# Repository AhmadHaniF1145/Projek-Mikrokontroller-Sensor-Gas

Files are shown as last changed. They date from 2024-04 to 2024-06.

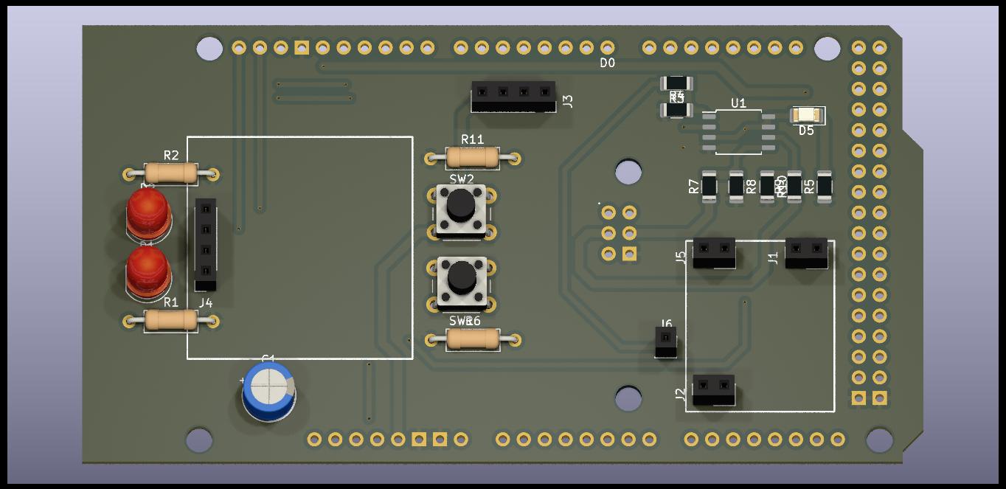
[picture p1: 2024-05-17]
Assets/PCB Design/Pre/3D PCB Design/2.jpg

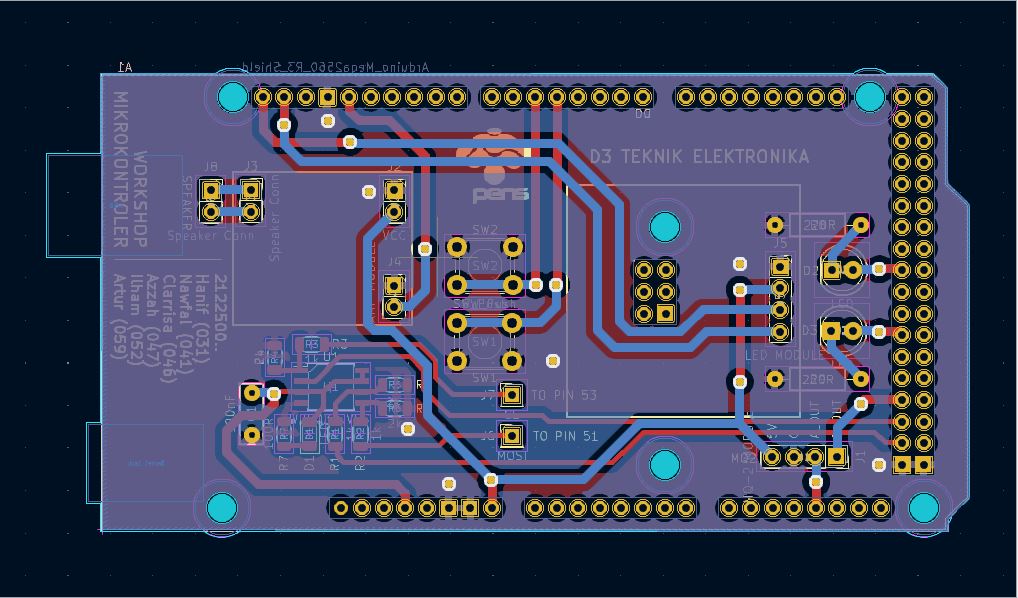
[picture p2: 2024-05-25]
Assets/PCB Design/Final/BOTTOM.JPG

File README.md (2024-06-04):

banner-dg-logo
Sistem pendeteksi kebocoran gas adalah sistem elektronik yang dirancang untuk mendeteksi dan memberi peringatan tentang kebocoran gas. Peringatan yang dihasilkan adalah dalam bentuk audio sesuai gas yang dideteksi beserta tingkat bahayanya.

`WORKSHOP MIKROKONTROLLER - PROGRAM STUDI TEKNIK ELEKTRONIKA - POLITEKNIK ELEKTRONIKA NEGERI SURABAYA`

`DOSEN PENGAMPU : Akhmad Hendriawan ST, MT`
`NIP. 197501272002121003`

`TEAM`
| No.  | Nama  | NRP  | Pembagian Tugas  |
| :---: | :---: | :---: | :---: |
| 1  | Ahmad Hanif Abiyyu Khrisna  | 2122500031  | Pengujian Sistem Pada Software, Pengujian Alat  |
| 2  | Nawfal Ulinnuha F  | 2122500041  | Publikasi melalui Github, Pembelian Hardware  |
| 3  |  Clarrisa Fitria A  | 2122500046  |  Studi Literatur, Pembuatan Audio Project |
| 4  |  Fatimah Azzahro |  2122500047 | Publikasi melalui Github, Pembuatan Audio Project |
| 5  |  Muhammad Ilham K | 2122500052  |  Desain 3D, Proses Perakitan dan Soldering, Proses Pemrograman Arduino |
| 6  | Artur Ferdiansyah  |  2122500059 | Desain Skematik dan PCB Board, Proses Perakitan dan Soldering, Proses Pemrograman Arduino  |

## Daftar Isi
- [Komponen Yang Digunakan](#Komponen-Yang-Digunakan)
- [Konsep Simulasi](#Konsep-Simulasi)
- [Skematik Rangkaian](#Skematik-Rangkaian)
- [Informasi Penempatan Modul dan Komponen](#Informasi-Penempatan-Modul-dan-Komponen)
- [Audio Project](#Audio-Project)
- [Proses Pengerjaan](#Proses-Pengerjaan)
- [Hasil](#Hasil)
- [Cara Penggunaan Alat](#Cara-Penggunaan-Alat)

## Komponen Yang Digunakan
1. Arduino Mega 2560
2. Gas Sensor MQ2
3. OLED 0.96 Inch
4. Push Button
5. LED 3mm
6. SMD LED 1206
7. Speaker/Buzzer
8. Modul amplifier PAM8403
9. IC SPI Flash W25Q32JVSSIQ (4MB)

Dan Beberapa komponen pasif seperti resistor yang salah satunya digunakan sebagai pembatas arus pada LED indikator, dan kapasitor yang digunakan pada blok rangkaian SPI Flash Eksternal yang digunakan sebagai penyimpanan data tambahan.

## Blok Diagram
blok-diagram
Prinsip kerja dari sistem pendeteksi kebocoran gas yaitu dimulai dengan sistem pertama kali digunakan dimana sumber daya berasal dari baterai. Ketika tidak terdeteksi kebocoran gas, maka LED hijau akan selalu menyala. Ketika kebocoran gas terdeteksi oleh sensor MQ-2 dengan threshold yang telah disetting oleh push button 1, maka speaker mengeluarkan audio. Untuk informasi threshold yaitu threshold 400 dan 600 masih dalam level siaga dengan indikasi audio "terdeteksi kebocoran gas hati-hati siaga", kemudian threshold 800 sudah dalam level bahaya dengan indikasi audio "bahaya, bahaya, bahaya terdeteksi kebocoran gas". LCD OLED digunakan untuk menampilkan informasi threshold dan banyaknya gas yang terdeteksi. Jika gas yang terdeteksi melebihi threshold, maka speaker mengeluarkan audio dibarengi dengan LED merah yang juga ikut menyala. Untuk mematikan speaker, digunakan push button 2 dan LED hijau kembali menyala yang berarti kondisi sudah diatasi atau sudah aman.

## Konsep Simulasi
Berikut adalah skematik breadboard untuk simulasi menggunakan TinkerCad yang menggunakan Arduino Uno.

https://github.com/AhmadHaniF1145/Projek-Mikrokontroller-Sensor-Gas/assets/168633171/c68b0559-28a6-41bc-bea3-4cfa7fe1158b

## Skematik Rangkaian
Berikut ini adalah hasil skematik rangkaian sistem pendeteksi kebocoran gas menggunakan software KiCad.

Schematic - Pre

Berikut adalah link tutorial dalam pembuatan skematik menggunakan KiCad bisa dilihat pada video [berikut.](https://youtu.be/a5kBzt2_dH4 "berikut.") Untuk semua file yang dibutuhkan terkait skematik rangkaian bisa diakses pada link [berikut.](https://github.com/AhmadHaniF1145/Projek-Mikrokontroller-Sensor-Gas/tree/main/PCB%20Board "berikut.")

## Desain 3D
Berikut ini adalah hasil [desain 3D](https://github.com/AhmadHaniF1145/Projek-Mikrokontroller-Sensor-Gas/tree/main/Desain%203D "Desain 3D") :
1. Desain 3D Casing <br>
<br>
2. Desain 3D Casing + Komponen <br>
<br>
3. Desain 3D PCB dengan Komponen <br>
<br>
4. Desain 3D PCB tanpa Komponen <br>
<br>

Berikut adalah video tutorial pembuatan desain casing menggunakan Autodesk Fusion versi sederhana. Klik link [youtube berikut](https://youtu.be/2gopSfegvmg?si=Se-gvMHZY0zX1dgN "youtube berikut")

Berikut adalah tutorial dalam pembuatan desain PCB menggunakan KiCad pada proyek ini. Bisa klik link [berikut.](https://youtu.be/dg8yomkr-xE "berikut.")

Asset 3D yang sudah jadi dapat di download pada [link Thingiverse berikut](https://www.thingiverse.com/thing:6621092 "link Thingiverse berikut")

## Informasi Penempatan Modul dan Komponen
Tata letak dan informasi terkait penempatan Modul dan Komponen untuk memudahkan pengguna dalam melakukan perakitan <br>
<br>

## Manufacture Drawing untuk Casing
Berikut adalah detail ukuran casing untuk kebutuhan manufaktur
<br>

https://github.com/AhmadHaniF1145/Projek-Mikrokontroller-Sensor-Gas/assets/91182185/3b76fa04-874f-4a73-a389-29a3c4dec217

## Program
Program utama dari projek ini dibagi menjadi dua, yaitu :
- [Arduino dengan C](https://github.com/AhmadHaniF1145/Projek-Mikrokontroller-Sensor-Gas/tree/main/ProgramUtama/Program%20Utama_PlatformIO "Arduino dengan C")
- [Arduino dengan Bare Metal Programming.](https://github.com/AhmadHaniF1145/Projek-Mikrokontroller-Sensor-Gas/tree/main/ProgramUtama/Program%20Utama_Bare%20Metal_PlatformIO "Arduino dengan Bare Metal Programming.")

#### Timer 0
Projek ini memakai Timer 0 untuk memainkan suara yang disimpan pada Flash Memory (dibahas lebih lanjut pada [bagian audio project](## Audio Project "bagian audio project")). Berikut adalah baris kode utama untuk memainkan audio melalui sinyal PWM melalui Timer 0.
`OCR0A = sounddata_length + lastSample - sample;`

#### EEPROM
Alat ini dapat mendeteksi gas dengan Threshold (batas deteksi) yang berbeda sesuai yang diinginkan. Pengguna dapat menekan tombol kiri untuk mengganti mode Threshold. Mode yang diatur akan disimpan pada EEPROM.
`eeprom_write_byte((uint8_t*)0, thresholdIndex);`

Kemudian dibaca menggunakan
`int pilihanLagu = eeprom_read_byte((uint8_t*)0);`

## Audio Project
[Audio Project](https://github.com/AhmadHaniF1145/Projek-Mikrokontroller-Sensor-Gas/tree/main/Audio_Project "Audio Project")
Terdapat 2 mode audio sebagai deteksi adanya kebocoran gas, yaitu :
1. Terdeteksi kebocoran gas hati-hati siaga
2. Bahaya, bahaya, bahaya terdeteksi kebocoran gas

Berikut hasil pembuatan audio dengan hasil editnya menggunakan software Audacity yang kemudian didapatkan file raw yang dibuka melalui software HxD untuk memperoleh datanya dan didapatkan program bahasa C. Program bahasa C tersebut digunakan untuk memrogram Arduino ATMega 2560 agar audio berfungsi. Berikut hasil dokumentasinya  :
1. Terdeteksi kebocoran gas hati-hati siaga <br>
<br>
<br>
<br>
Hasil audio sebelum dan sesudah diedit menggunakan software Audacity [di sini](https://youtu.be/VL2fVMhNUZw "di sini").
2. Bahaya, bahaya, bahaya terdeteksi kebocoran gas <br>
<br>
<br>
<br>
Hasil audio sebelum dan sesudah diedit menggunakan software Audacity [di sini](https://youtu.be/l1GMS38mKNk "di sini").
3. Video Tutorial : Langkah - Langkah Convert Audio Ke Bahasa C

   https://github.com/AhmadHaniF1145/Projek-Mikrokontroller-Sensor-Gas/assets/168683498/8abb6570-371c-4412-ba63-2867d9131914

## Proses Pengerjaan
Berikut dokumentasi pada proses pengerjaan. [Dokumentasi](https://github.com/AhmadHaniF1145/Projek-Mikrokontroller-Sensor-Gas/tree/main/Dokumentasi "Dokumentasi")
1. Studi Literatur <br>
   <br>
2. Pengujian Sistem Pada Software <br>
   <br>
3. Pembuatan Desain Skematik dan PCB Board <br>
   <br>
4. Pembuatan 3D Desain <br>
   <br>
5. Pembelian Hardware <br>
   <br>
6. Proses Perakitan dan Soldering <br>
   <br>
7. Proses Pembuatan Audio <br>
   <br>
8. Proses Pemrograman Arduino <br>
   <br>
9. Pengujian Alat <br>
    <br>
10. Publikasi GitHub <br>
   <br>

## Hasil
1. PCB Print <br>
   <br>
2. 3D Print <br>
   <br>

## Cara Penggunaan Alat

https://github.com/AhmadHaniF1145/Projek-Mikrokontroller-Sensor-Gas/assets/91182185/28567a20-36dd-4a8e-a68d-8d7cb96f8bae

1. Pastikan baterai dalam kondisi penuh kemudian pasang baterai pada tempatnya yaitu di dalam casing. Tutup kemasan dengan benar.
2. Pasang LCD OLED di tempatnya yaitu di luar casing.
3. Nyalakan power switch.
4. Atur threshold sesuai kebutuhan menggunakan push button sebelah kanan. Untuk informasi threshold sebagai berikut.
   Semakin besar nilai threshold maka kebocoran gas yang dideteksi semakin banyak dan bahaya.
   Semakun kecil nilai threshold maka sedikit saja kebocoran gas dapat terdeteksi.
6. Alat sudah siap digunakan untuk mendeteksi kebocoran gas dengan indikator LED hijau menyala jika tidak ada kebocoran gas yang terdeteksi.
7. Apabila sensor telah mendeteksi gas melebihi threshold yang diatur, maka LED warna merah dan audio menyala berulaang-ulang tergantung threshold yang disetting.
   threshold 400 dan 600 dalam level siaga dengan audio "Terdeteksi kebocoran gas hati-hati siaga"
   threshold 800 dalam level bahaya dengan audio "Bahaya, bahaya, bahaya terdeteksi kebocoran gas"
8. Audio bisa dimatikan dengan menekan push button sebelah kiri kemudian LED yang menyala berganti menjadi warna hijau kembali.
Untuk video pengujian alat ini dengan versi HD bisa dilihat pada link [berikut ini](https://youtu.be/NTNdcy7BNHo)

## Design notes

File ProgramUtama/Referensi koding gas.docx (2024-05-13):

1. https://youtu.be/cmL7QgTNv7M?si=9J4_7mAFtSgwZmdm

#include <MQ2.h>

#include <Wire.h>

#include <LiquidCrystal_I2C.h>

LiquidCrystal_I2C lcd(0x27, 16, 2);

int Analog_Input = A0;

int lpg, co, smoke;

MQ2 mq2(Analog_Input);

void setup() {

Serial.begin(9600);

lcd.begin();

lcd.backlight();

mq2.begin();

}

void loop() {

float* values = mq2.read(true);

lpg = mq2.readLPG();

co = mq2.readCO();

smoke = mq2.readSmoke();

lcd.setCursor(0, 0);

lcd.print("LPG:");

lcd.print(lpg);

lcd.print(" CO:");

lcd.print(co);

lcd.setCursor(0, 1);

lcd.print("SMOKE:");

lcd.print((smoke * 100) / 1000000);

lcd.print(" %");

delay(1000);

}

2. https://youtu.be/pF7xslWYlwE?si=qWiCOMXyJoNRGcOX

#include <FirebaseESP32.h>

#include <WiFi.h>

#define FIREBASE_HOST "https://deteksi-asap-mq2-lawlaw-elc-default-rtdb.firebaseio.com/"

#define FIREBASE_AUTH "chH5OCJQ9oSiPmKkJA3QKbtesceoYBB2U9cApdDb"

#define WIFI_SSID "LAWLAW ELC"

#define WIFI_PASSWORD "tolongsubcribe"

FirebaseData fbdo;

#define PinDigital 4

int NilaiDigital;

void setup() {

Serial.begin(9600);

pinMode(PinDigital, INPUT);

WiFi.begin(WIFI_SSID, WIFI_PASSWORD);

Serial.print("Menghubungkan Wi-Fi");

while (WiFi.status() != WL_CONNECTED) {

Serial.print(".");

delay(300);

}

Serial.println();

Serial.print("terhubung dengan WiFi IP: ");

Serial.println(WiFi.localIP());

Serial.println();

Firebase.begin(FIREBASE_HOST, FIREBASE_AUTH);

}

void loop() {

NilaiDigital = digitalRead(PinDigital);

Serial.print("Nilai Output Digital = ");

Serial.println(NilaiDigital);

Firebase.setFloat(fbdo, "/Nilai_Asap", NilaiDigital);

if (NilaiDigital == 0) {

Firebase.setString(fbdo, "/Kondisi", "Ada Asap");

} else {

Firebase.setString(fbdo, "/Kondisi", "Aman");

}

delay(1000);

}

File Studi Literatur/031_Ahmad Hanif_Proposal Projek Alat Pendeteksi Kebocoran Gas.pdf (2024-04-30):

Sistem Pendeteksi Kebocoran Gas berbasis Mikrokontroller AVR dengan Output Audio

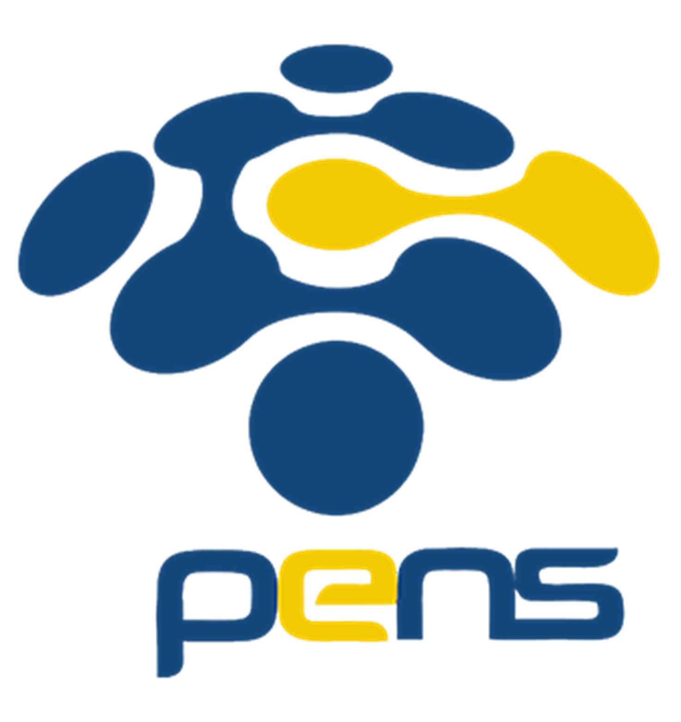
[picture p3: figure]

Disusun oleh :
Ahmad Hanif Abiyyu Khrisna (2122500031)

POLITEKNIK ELEKTRONIKA NEGERI SURABAYA TEKNIK ELEKTRONIKA
2023-2024

iii

DAFTAR ISI

DAFTAR GAMBAR

DAFTAR TABEL

1

BAB 1. PENDAHULUAN

### 1.1 Latar Belakang

Penggunaan gas LPG merupakan salah satu faktor terjadinya kebakaran apabila tidak digunakan dengan berhati-hati, terutama saat pemasangan tabung LPG dan beredarnya tabung gas yang palsu namun menggunakan logo SNI (Standar Nasional Indonesia). Ada kasus kebakaran yang terjadi karena kebocoran LPG, yaitu kebakana yang terjadi dirumah warga tepatnya di Lembang Buntu Tabang, Kecamatan Gandang Batu Sillanan, Tana Toraja pada tahun 2019 lalu. Kejadian terjadi karena pemasangan tabung LPG yang tidak benar sehingga setelah pemasangan tabung LPG tersebut meledak sehingga membakar bagian dapur dan menyebar ke bagian rumah yang lainnya. Hal ini terjadi karena adanya kebocoran gas pada tabung LPG sehingga saat ada percikan api maka membuat gas yang menguap terbakar dan membuat tabung LPG tersebut terbakar.
Mikrokontroler AVR merupakan pilihan populer untuk sistem embedded, termasuk sistem pemantauan kebocoran gas. Alasannya adalah karena AVR memiliki beberapa keunggulan, seperti:
- Hemat biaya: AVR adalah mikrokontroler yang relatif murah dan mudah diakses.
- Mudah digunakan: AVR mudah diprogram dan digunakan, sehingga ideal untuk proyek DIY.
- Hemat daya: AVR memiliki konsumsi daya yang rendah, sehingga ideal untuk aplikasi portabel.
- Performa yang cukup: AVR memiliki performa yang cukup untuk aplikasi pemantauan kebocoran gas sederhana.
- Penggunaan AVR dalam Sistem Pemantauan Kebocoran Gas
Dalam sistem pemantauan kebocoran gas, AVR dapat digunakan untuk:
- Membaca data dari sensor gas: AVR dapat membaca data dari sensor gas dan mengubahnya menjadi sinyal digital.
- Memproses data sensor: AVR dapat memproses data sensor untuk mendeteksi kebocoran gas.
- Mengaktifkan alarm: Jika kebocoran gas terdeteksi, AVR dapat mengaktifkan alarm.
- Menyimpan data: AVR dapat menyimpan data sensor dan informasi lainnya untuk analisis lebih lanjut.
Proyek ini yaitu merancang alat pendeteksi kebocoran gas berbasis Arduino Nano dimana alat yang dibuat dapat mendeteksi adanya kebocoran gas, asap, dan api menggunakan sensor MQ-2. Alat yang dibuat dilengkapi buzzer dan speaker akan secara otomatis hidup ketika mendeteksi adanya kebocoran gas dan apabila ada percikan api dari kebocoran gas.

2

Format audio raw 8 bit 1 channel mono adalah format audio digital yang menggunakan 8 bit untuk mewakili setiap sampel audio. Format ini hanya memiliki satu channel audio, yaitu mono. Format ini sering digunakan untuk aplikasi sederhana seperti rekaman suara dan playback audio.
Sampling rate adalah jumlah sampel audio yang diambil per detik. Sampling rate diukur dalam Hertz (Hz). Sampling rate yang lebih tinggi menghasilkan kualitas audio yang lebih baik, tetapi juga membutuhkan lebih banyak ruang penyimpanan.
Tujuan dari penelitian ini yaitu merancang dan mengaplikasikan alat untuk mendeteksi kebocoran gas LPG menggunakan sensor MQ-2, buzzer, speaker, dan Arduino Nano. Mengetahui fungsi dan karakteristik dari sensor MQ-2 berdasarkan pengujian. Mengetahui cara memproses audio dalam pada mikrokontroller AVR untuk digunakan sebagai alarm peringatan adanya kebocoran gas.

3

BAB 2. TINJAUAN PUSTAKA

### 2.1 Deskripsi Proyek

Sistem pendeteksi kebocoran gas adalah sistem elektronik yang dirancang untuk mendeteksi dan memberi peringatan tentang kebocoran gas. Sistem ini menggunakan sensor gas yaitu MQ-2 untuk mendeteksi keberadaan gas berbahaya, seperti LPG, metana, dan karbon monoksida. Jika kebocoran gas terdeteksi, sistem akan mengaktifkan alarm untuk memperingatkan pengguna jika terjadi kebocoran gas.
Pada alat ini tersimpan file audio yang isinya yaitu rekaman audio peringatan yang sudah kita format menggunakan software audacity. Format settingnya yaitu format raw 8 bit, 1 channel mono, dan sampling rate 8kHz yang mana format-format ini sudah disetting pada software Audacity.

### 2.2 Rancangan Sistem

### 2.2.1 Perancangan Perangkat Keras

Dalam desain perangkat keras, akan dilakukan perancangan perangkat keras yang dibutuhkan untuk membangun sistem pendeteksi kebocoran gas LPG. Gambar dibawah merupakan rancangan system pendeteksi gas LPG.

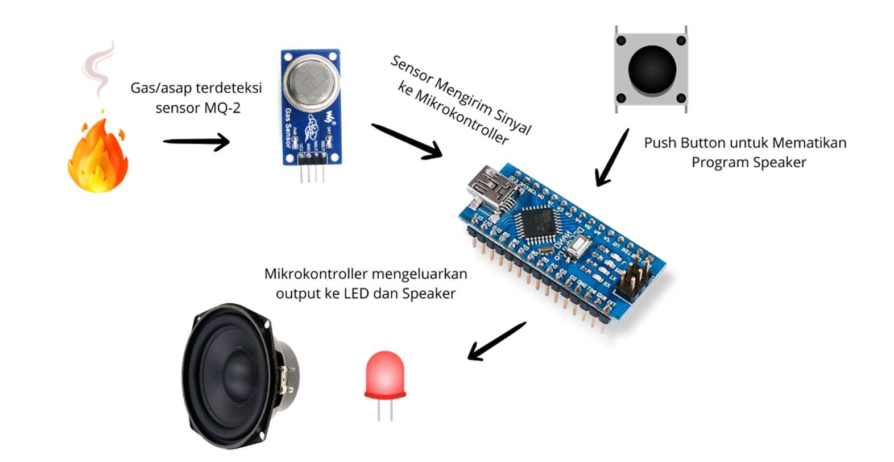
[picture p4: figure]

Gambar 2.1. Perancangan Perangkat Keras

Pada gambar diatas ada beberapa bahan dan alat yang dibutuhkan yaitu;

### 1. Mikrokontroller Arduino Nano

Arduino Nano adalah papan mikrokontroler kecil dan lengkap yang didasarkan pada mikrokontroler ATmega328P dari keluarga AVR. Memiliki 32 pin I/O digital terdapat 6 pin PWM, 6 pin analog, dan kristal 16kHz.

### 2. Sensor MQ-2

Sensor MQ-2 digunakan untuk mendeteksi gas LPG, ibutana, propana, metana, alkohol, hidrogen dan asap. Dari datasheet, inti dari MQ-2 adalah

4

material yang sensitif terhadap konsentrasi gas yang tersusun dari senyawa SnO2 atau dalam istilah kita disebut Timah (IV) Oksida. Material ini memiliki karakteristik akan berubah konduktivitasnya seiring dengan perubahan konsentrasi gas di sekitarnya.Loadspeaker Buzzer

### 3. Speaker

Speaker adalah perangkat elektronik yang mengubah sinyal listrik menjadi gelombang suara. Speaker bekerja dengan cara menggerakkan membran atau konus di dalamnya sesuai dengan sinyal listrik yang diterimanya, sehingga menghasilkan getaran udara yang kita dengar sebagai suara

### 4. LED

LED (Light Emitting Diode) adalah semikonduktor yang menghasilkan cahaya saat arus listrik melewatinya. Berbeda dengan lampu pijar yang menggunakan filamen untuk menghasilkan cahaya, LED menghasilkan cahaya melalui proses elektroluminensi diode semikonduktor.

### 5. Push Button

Push button adalah jenis saklar sederhana yang digunakan untuk menghubungkan atau memutuskan arus listrik dalam rangkaian elektronik Setelah alat dan bahannya sudah fix maka bisa dibuat skematik dan PCB board menggunakan software KiCad agar hasil akhir prototype alatnya menjadi compact dan portable untuk dibawa dan ditaruh dimana pun.

### 2.2.2 Perancangan Perangkat Lunak

Perancangan program sistem pendeteksi kebocoran gas ini terdiri dari beberapa tahapan. Proses pertama adalah pembuatan flowchart dari sistem pendeteksi kebocoran gas, kemudian program dibuat menggunakan Arduino IDE menggunakan bahasa C. Kemudian program di upload ke mikrokontroler dari software Arduino IDE.

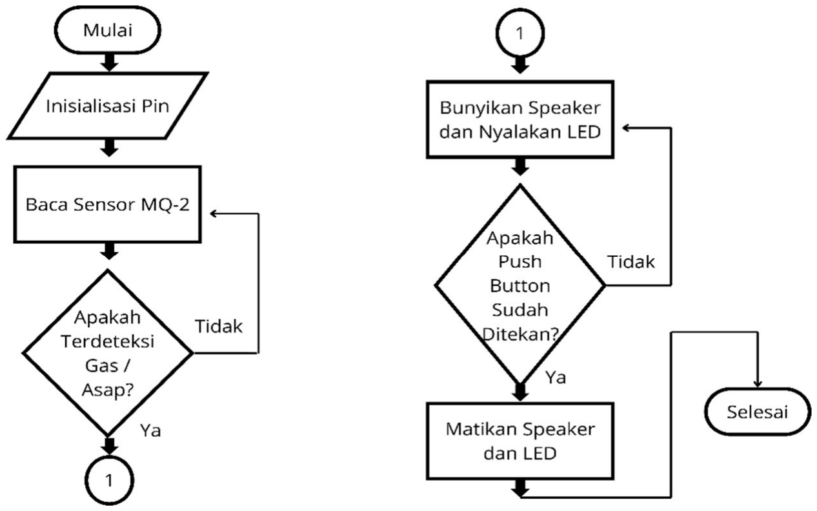
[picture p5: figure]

Gambar 2. 2. Flow Chart

5

BAB 3. TAHAP PELAKSANAAN

### 3.1 Tahap Pelaksanaan

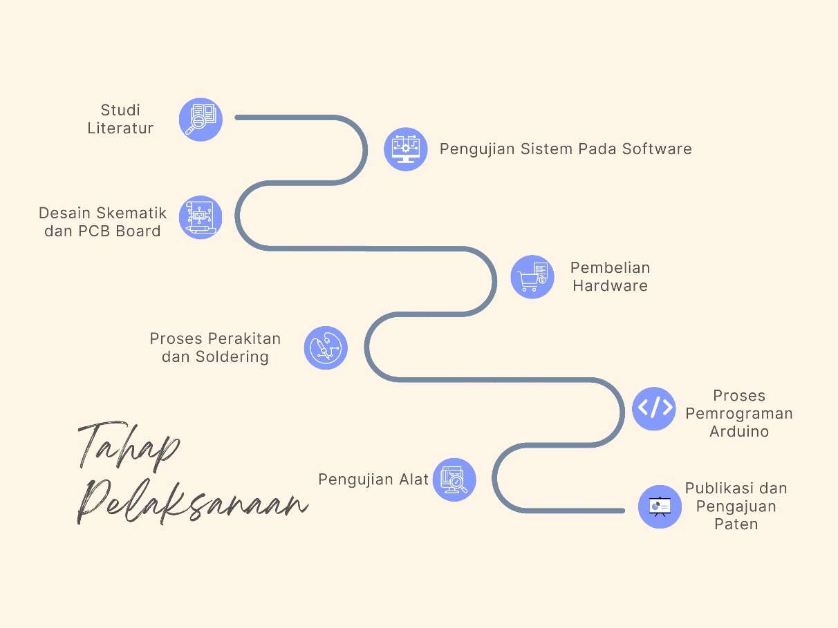
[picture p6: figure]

Gambar 3.1. Road Map

### 3.1.1 Studi Literatur

Pada tahap ini dilakukan studi literatur yaitu mencari dan mempelajari beberapa informasi, baik dari segi software dan hardware untuk memperoleh teori dan metode yang dapat mendukung serta efektif dalam perancangan pembuatan prototype alat pendeteksi kebocoran gas. Studi literatur ini dapat berasal dari buku, jurnal, artikel, dan website.

### 3.1.2 Pengujian Sistem Pada Software

Pada tahap ini dilakukan pengujian sistem rangkaian alatnya menggunakan software, bisa pada website seperti wokwi dan thinkercad, bisa juga menggunakan software proteus dan lainnya. Pada tahap ini pertama kita tambahkan part yang akan digunakan seperti mikrokontroller AVR, sensor MQ-2, Speaker, LED, Push Button, dan Breadboard, setelah semua sudah ditambahkan maka kita bisa wiring part tadi sesuai dengan skematik dan datasheet.

### 3.1.3 Desain Skematik dan PCB Board

Pada tahap ini kami membuat skematik untuk seluruh part menggunakan software KiCad, kemudian dari skematik kami membuat desain PCB board dengan wiring.

6

### 3.1.4 Pembelian Hardware

Pada tahap ini karena sudah dibuat desain skematik dan PCB boardnya maka sudah fix alat dan bahan yang akan digunakan pada sistem pendeteksi kebocoran gas ini dibeli sesuai kebutuhan.

### 3.1.5 Proses Perakitan dan Soldering

Pada tahap proses perakitan dilakukan beberapa tahapan yaitu pemasangan seluruh komponen pada PCB board mulai dari yang paling kecil sampai besar, kemudian proses soldering komponen yang bisa disolder dan proses soldering harus sudah sesuai standar elektronika seperti pemberian flux dan lainnya.

### 3.1.6 Proses Pemrograman Arduino

Pada tahap proses pemrograman arduino ini kami menggunakan software Arduino IDE untuk platform kodingnya, saat pertama kali masuk Arduino IDE kita pilih board sesuai board yang kita pakai yaitu arduino nano, dan cek kembali port COM serial yang tepat, pada tahap ini juga dilakukan perekaman audio sebagai audio peringatan untuk alarm kebocoran gas, proses format audio ini menggunakan software audacity dan disetting sesuai yang dibutuhkan seperti channel mono stereo, format raw 16bit – 32bit, sampling rate 8kHz-384kHz.

### 3.1.7 Pengujian Alat

Pada tahap pengujian alat ini artinya alat pendeteksi kebocoran gas yang kami buat sudah selesai di rakit dan di koding, pada proses ini kita hanya menguji alatnya ketika diberikan gas seperti pada korek api apakah alat ini berfungsi sesuai dengan konsepnya atau tidak, jika ada beberapa masalah maka solusinya trial & error dan quality control.

### 3.1.8 Publikasi dan Pengajuan Paten

Pada tahap publikasi dan pengajuan paten dilakukan dokumentasi untuk di upload pada sosial media seperti instagram dan pengajuan hak paten untuk melindungi hak kekayaan intelektual dan menghindari pencurian teknologi yang telah dicapai selama proses pembuatan.

7

### 3.2 Implementasi 3.2.1 Pengaturan Timer

- Menggunakan timer mikrokontroler AVR untuk mengatur interval pengambilan data sensor gas.
- Pengaturan timer dapat dilakukan dengan menggunakan register kontrol timer (TCNT, OCR) dan mode timer yang sesuai (CTC, PWM).
- Interval pengambilan data harus disesuaikan dengan sensitivitas sensor gas dan kebutuhan proyek.

### 3.2.2 Pengaturan Pin Interrupt

- Konfigurasikan pin sensor gas sebagai input dengan mengaktifkan interupsi eksternal.
- Mengatur tepi interupsi (rising edge, falling edge) sesuai dengan jenis sensor gas yang digunakan.
- Interupsi akan dipicu ketika sensor mendeteksi kebocoran gas, dan fungsi interupsi akan dijalankan untuk memproses data sensor.

### 3.2.3 Pemrosesan Audio

- Setelah interupsi dipicu, baca nilai sensor gas dan bandingkan dengan nilai ambang batas yang ditentukan.
- Jika nilai sensor melebihi ambang batas, maka kebocoran gas terdeteksi.
- menggunakan pustaka audio atau fungsi PWM untuk menghasilkan suara peringatan.
- Durasi dan frekuensi suara peringatan dapat disesuaikan sesuai kebutuhan.

### 3.24 Tombol Push Button

- Hubungkan tombol push button ke pin I/O mikrokontroler.
- Konfigurasikan pin tombol push button sebagai input dengan mengaktifkan interupsi eksternal.
- Interupsi akan dipicu ketika tombol ditekan, dan fungsi interupsi akan dijalankan untuk melakukan tindakan yang diinginkan.
- Push Button ini bisa mematikan suara peringatan.

8

BAB 4. JADWAL KEGIATAN dan ANGGARAN DANA

### 4.1 Jadwal Kegiatan

Tabel 4.1. Jadwal Kegiatan
No | Jenis Kegiatan | Minggu | Penanggung Jawab
8-9 | 10-11 | 12-13 | 14-15
1 | Studi Literatur | | | 1. Ahmad Hanif
2 Pengujian Sistem | Pada Software | | | 1. Ahmad Hanif
3 Desain Skematik | dan PCB Board | | | 1. Ahmad Hanif
4 Pembelian | Hardware | | | 1. Ahmad Hanif
5 Proses Perakitan | dan Soldering | | | 1. Ahmad Hanif
6 Proses | Pemrograman Arduino | | | 1. Ahmad Hanif
7 | Pengujian Alat | | | 1. Ahmad Hanif
8 Publikasi dan | Pengajuan Paten | | | 1. Ahmad Hanif

9

### 4.2 Anggaran Dana

Tabel 4.2. Anggaran Dana
No | Jenis Pengeluaran | Volume | Harga Satuan (Rp) | Total (Rp)

1 Belanja Bahan

| Arduino Nano V3 | 1 | 60.000 | 60.000
| Sensor MQ-2 | 1 | 20.000 | 20.000
| Speaker | 1 | 40.000 | 40.000
| LED | 2 | 500 | 1.000
| Push Button | 3 | 1.000 | 3.000
| Transistor NPN | 1 | 1.500 | 1.500
SUB TOTAL | | 125.000

2 Belanja Sewa

| Cetak PCB Board | 1 | 50.000 | 50.000
SUB TOTAL | | 50.000

3 Perjalanan

| Biaya Ongkos Kirim Online Shop | 6 | 10.000 | 60.000
| Biaya Transportasi (Pembelian alat dan komponen) | 1 | 50.000 | 50.000
SUB TOTAL | | 110.000

4 Lain-lain

| Pengajuan Hak Paten | 1 | 250.000 | 250.000
SUB TOTAL | | 250.000
GRAND TOTAL | | 535.000

GRAND TOTAL (Terbilang Lima Ratus Tiga Puluh Lima Ribu Rupiah)

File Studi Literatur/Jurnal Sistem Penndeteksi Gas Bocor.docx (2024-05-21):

SISTEM PENDETEKSI KEBOCORAN GAS DENGAN OUTPUT AUDIO BERBASIS MIKROKONTROLLER ATMEGA 2560

Ahmad Hanif Abiyyu K(031), Nawfal Ulinnuha F(041), Clarrisa Fitria A(046), Fatimah Azzahro(047), Muhammad Ilham K(052), Artur Ferdiansyah(059)

Abstract - The Downstream Oil and Gas Regulatory Agency (BPH Migas) estimates that gas distribution through jargas in some areas still shows losses of up to 10%. In fact, ideally the percentage of leakage should be a maximum of 2%. Data from the Central Statistics Agency (BPS) shows that the majority or 86.91% of Indonesian households use gas fuel for cooking in 2023. Automatically, due to the considerable use of gas among households which can result in gas leaks that can propagate to explosions and also the distribution of natural gas by BPH Migas which has a fairly high leakage. This study aims to produce a gas leak detection system using the MQ-6 sensor as a gas sensor and also using the Atmega 2560 Microcontroller as its control center and using a speaker that emits 2 states of sound with different gas levels and the speaker will be active when it detects gas at a specified level. So that with this tool is expected to overcome various types of risks from gas leaks.

Intisari - Badan Pengatur Hilir Minyak dan Gas Bumi (BPH Migas) memperkirakan penyaluran gas melalui jargas di beberapa wilayah masih menunjukkan kebocoran (losses) hingga 10%. Padahal, idealnya persentase kebocoran maksimal 2%. Data Badan Pusat Statistik (BPS) menunjukkan, mayoritas atau 86,91% rumah tangga Indonesia menggunakan bahan bakar gas untuk memasak pada 2023. Secara otomatis, dikarenakan penggunaan gas yang cukup banyak dikalangan rumah tangga yang dapat mengakibatkan pada Kebocoran gas yang bisa merambat ke ledakan dan juga penyaluran gas bumi oleh BPH Migas yang terdapat kebocoran lumayan tinggi. Penelitian ini bertujuan untuk menghasilkan sistem pendeteksi kebocoran gas dengan menggunakan sensor MQ-6 sebagai sensor gas dan juga menggunakan Mikrokontroller Atmega 2560 sebagai pusat kontrolnya serta menggunakan speaker yang mengeluarkan 2 keadaan suara dengan level gas yang berbeda beda dan speaker tersebut akan aktif ketika mendeteksi gas di level yang ditentukan. Sehingga dengan alat ini diharapkan dapat menanggulangi berbagai jenis risiko dari kebocoran gas.

Kata Kunci – Sensor MQ-2, Mikrokontroller, Audio, Kebocoran Gas

I. PENDAHULUAN

Kebocoran gas adalah keluarnya gas yang tidak terkendali dari pipa atau wadah lainnya. Kebocoran gas adalah masalah serius dan saat ini diamati di banyak tempat seperti tempat tinggal, industri, dan kendaraan seperti Gas Alam Terkompresi (CNG), bus, mobil, dll. Liquefied petroleum gas (LPG), atau propana, adalah campuran gas hidrokarbon yang mudah terbakar yang digunakan sebagai bahan bakar di banyak aplikasi seperti rumah, asrama, industri, mobil, dan lain-lain. Sumber energi ini terutama terdiri dari propana dan butana yang merupakan senyawa kimia yang sangat mudah terbakar, gas-gas ini dapat terbakar dengan mudah. Oleh karena itu, kebocoran gas harus dideteksi dan dikendalikan untuk melindungi orang dari bahaya.

Salah satu keadaan yang dapat digunakan untuk mencegah sekaligus meminimalisir risiko yang diakibatkan karena kebocoran gas adalah dengan membuat sistem deteksi kebocoran gas otomatis yang dapat memberi peringatan pada orang sekitar adanya kebocoran gas mulai dari level kebocoran gas rendah hingga tinggi dengan 2 output suara yaitu “Terdeteksi kebocoran gas hati-hati siaga” dan “Bahaya, bahaya, bahaya terdeteksi kebocoran gas”. Adapun keadaan tersebut akan diatur melalui mikrokontroller Atmega 2560 dan juga Sensor MQ-2 sebagai sensor deteksi adanya kebocoran Gas.

II. METODOLOGI PENELITIAN
  II.1. Tinjauan Jurnal

SISTEM PENDETEKSI KEBOCORAN GAS DENGAN OUTPUT AUDIO 2

[SISTEM PENDETEKSI KEBOCORAN GAS DENGAN OUTPUT AUDIO ] May 20, 2024

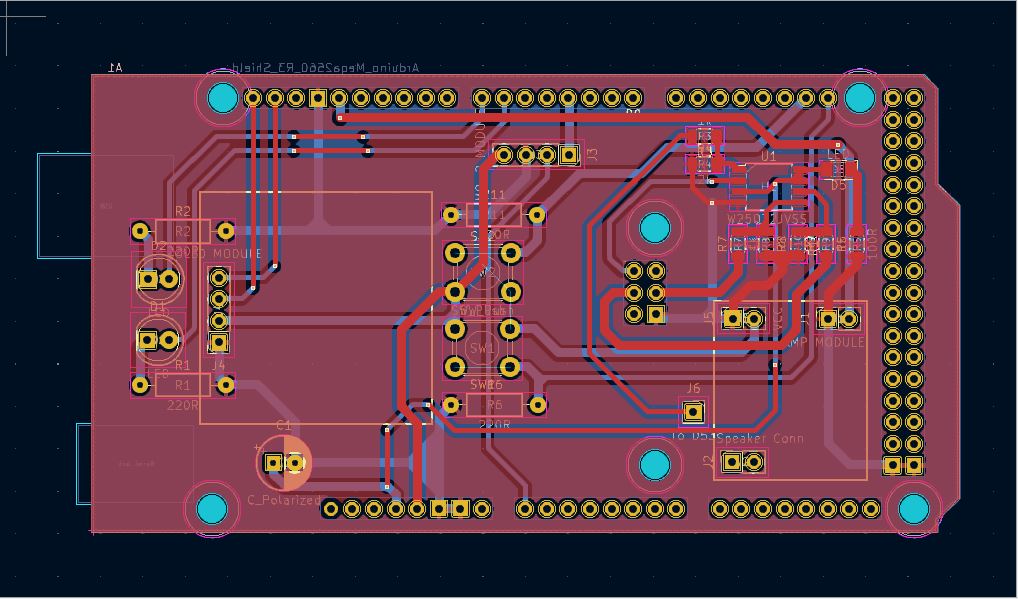
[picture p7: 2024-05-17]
Assets/PCB Design/Pre/PCB BOTTOM.JPG

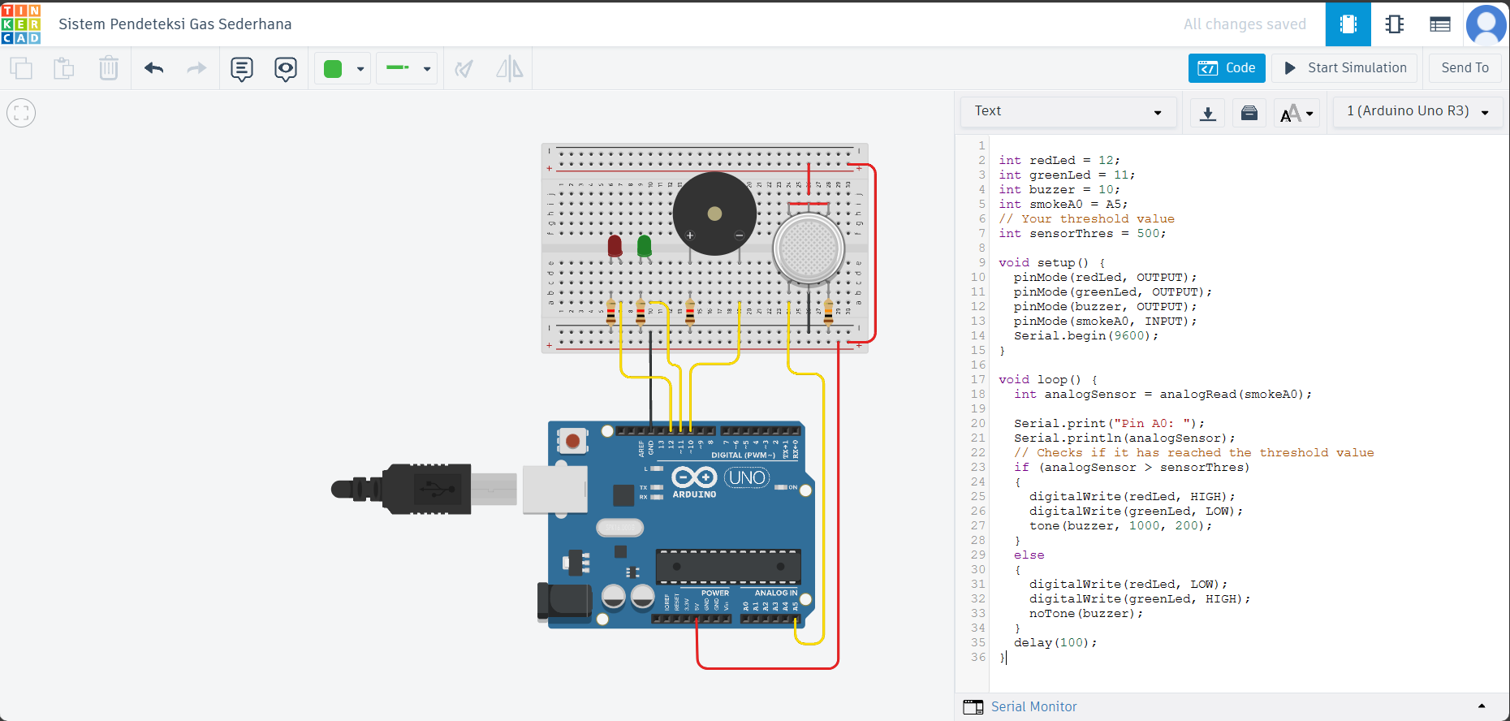
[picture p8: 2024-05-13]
Assets/Simulation and Schematic Design/Simulasi Sistem Pendeteksi Gas Sederhana.png

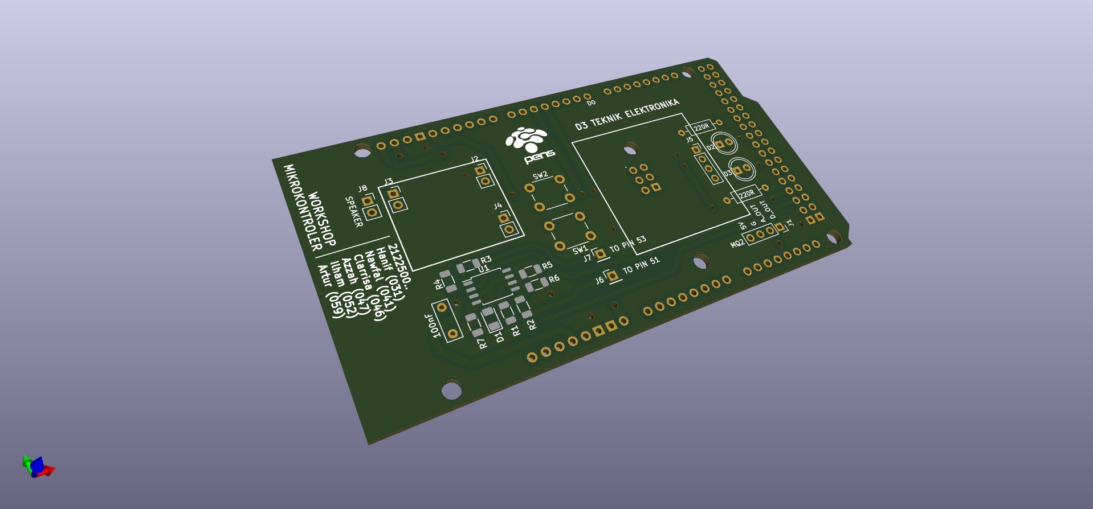
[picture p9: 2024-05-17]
Assets/PCB Design/Final/PCB 3D Model/3D Image tanpa komponen.png

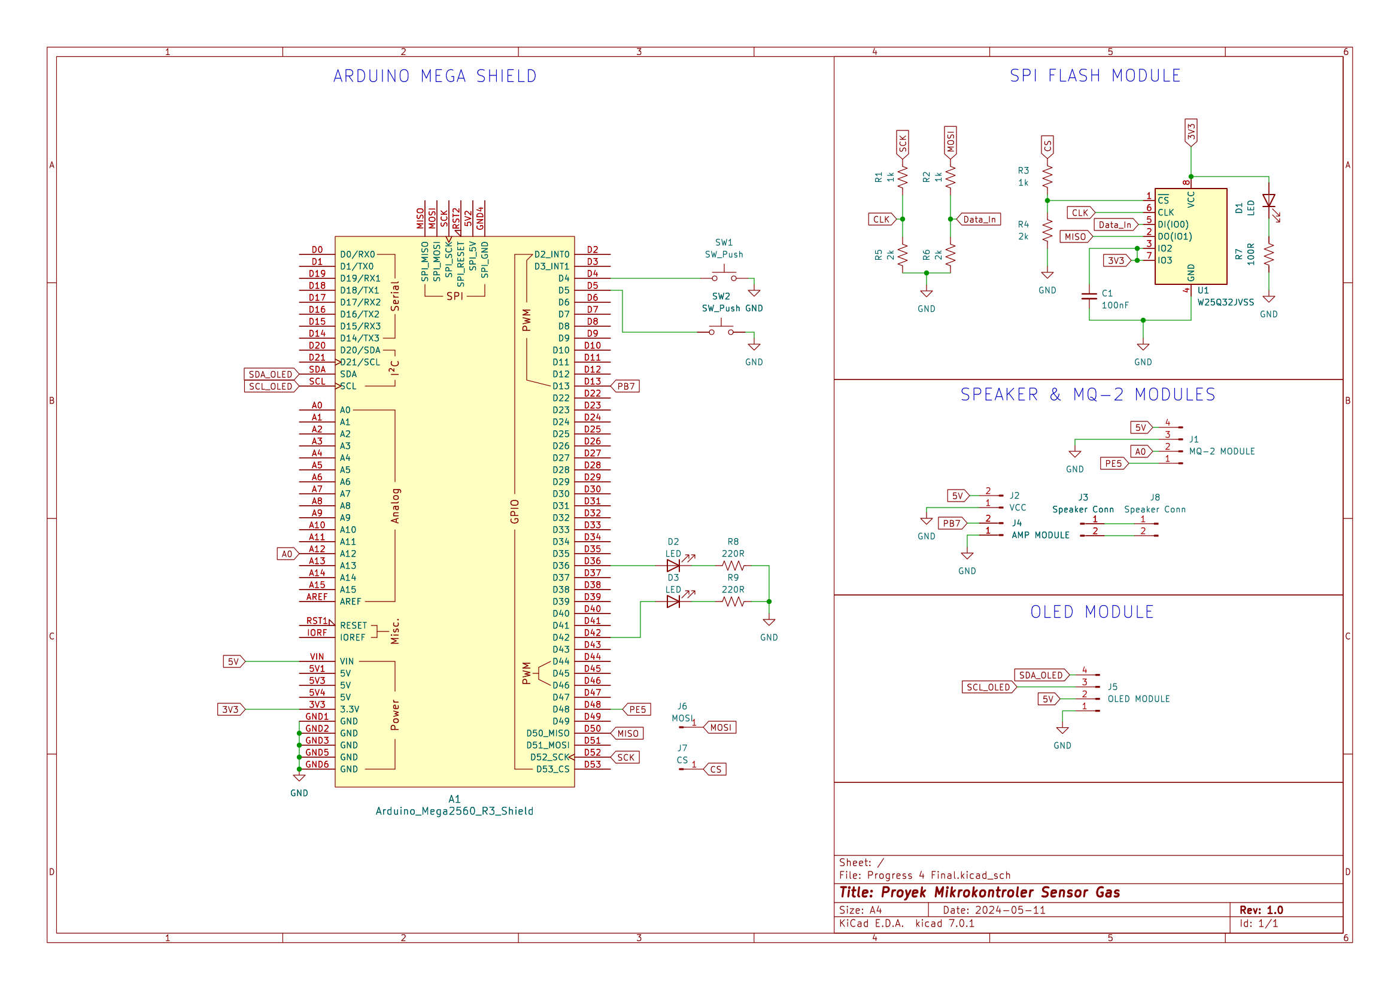
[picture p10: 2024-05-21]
Assets/Simulation and Schematic Design/Schematic - Final.png

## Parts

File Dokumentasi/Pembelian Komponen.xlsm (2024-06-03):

PENGELUARAN PEMBUATAN PROJECT |  |  |  |  | TOTAL PENGELUARAN
No. | Nama barang | Harga/satuan | Jumlah | Total | 216950
1 | MQ-2 | Rp. 18.000 | 1 | 18000
2 | Buzzer Alarm 12mm | Rp. 2.000 | 1 | 2000
3 | Button 6x6x5 4P | Rp. 200 | 2 | 400
4 | LED 3mm diffused red | Rp. 200 | 3 | 600
5 | LED 3mm diffused green | Rp. 200 | 3 | 600
6 | Header male single 1x40 | Rp. 1.000 | 3 | 3000
7 | Header female single 1x40 | Rp. 1.200 | 1 | 1200
8 | Cetak 3D | Rp. 70.400 | 1 | 70400
9 | Cetak PCB | Rp. 80.000 | 1 | 80000
10 | Print kalkir | Rp. 7.000 | 1 | 7000
11 | Push button 6x6x12 | Rp. 1.000 | 3 | 3000
12 | LED smd 1206 Putih | Rp. 150 | 5 | 750
13 | Resistor smd 1206 1K | Rp. 200 | 5 | 1000
14 | Resistor smd 1206 2K2 | Rp. 200 | 5 | 1000
15 | Kabel jumper F-F 20cm 10P | Rp. 4.000 | 1 | 4000
16 | 9v Battery addapter with jack | Rp. 2.000 | 1 | 2000
17 | Baut 3mm x 20mm | Rp. 400 | 10 | 4000
18 | Mur 3mm | Rp. 100 | 10 | 1000
19 | Resistor smd 1206 120 | Rp. 200 | 5 | 1000
20 | Universal Speaker 1.5 W | Rp. 16.000 | 1 | 16000

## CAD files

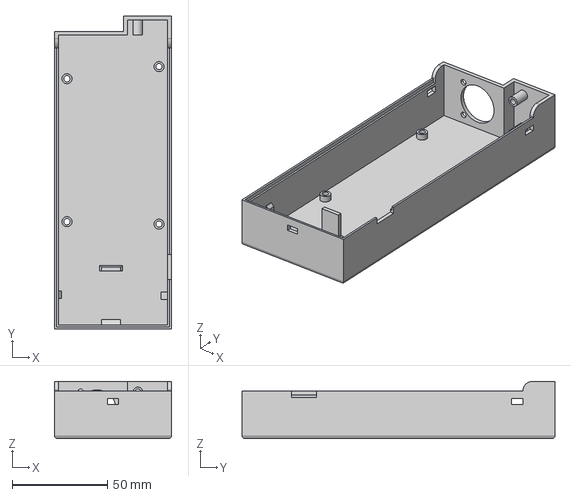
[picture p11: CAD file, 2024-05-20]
Desain 3D/Fusion 360 (Manufacture)/BAWAH.step
61.3 x 164.1 x 30.0 mm

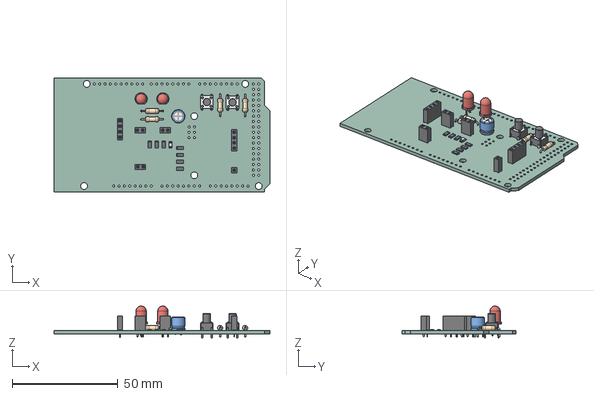
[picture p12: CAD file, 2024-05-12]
PCB Board/Progress 2/Project Hanip.step
102.1 x 53.9 x 15.1 mm
Project Hanip PCB

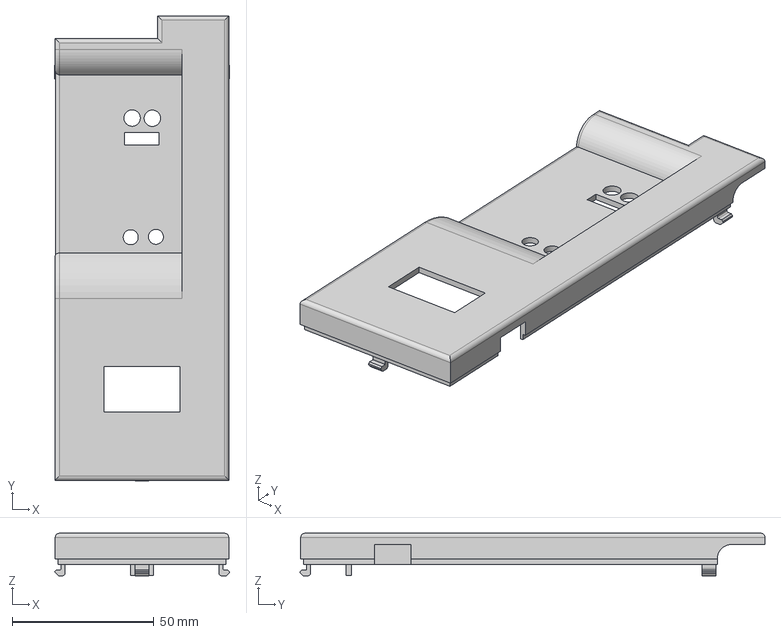
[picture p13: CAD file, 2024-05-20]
Desain 3D/Fusion 360 (Manufacture)/ATAS.step
61.8 x 164.3 x 15.0 mm

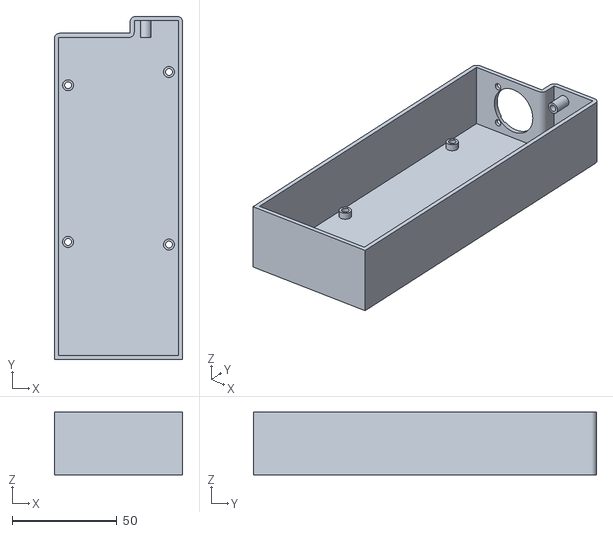
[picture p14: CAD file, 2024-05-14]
Desain 3D/Fusion 360 (Manufacture)/Casing Gas 3D v5.stl
61.3 x 164.1 x 30.0

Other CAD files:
PCB Board/Progress 3/3D File/Project Hanip.step
PCB Board/Progress 4 Final/3D File/Project 4 3D Model.step
Desain 3D/Fusion 360 (Manufacture)/ATAS rev1.step
Desain 3D/Fusion 360 (Manufacture)/BAWAH rev1.step
Desain 3D/Blender (Prototype)/alat 3d.blend

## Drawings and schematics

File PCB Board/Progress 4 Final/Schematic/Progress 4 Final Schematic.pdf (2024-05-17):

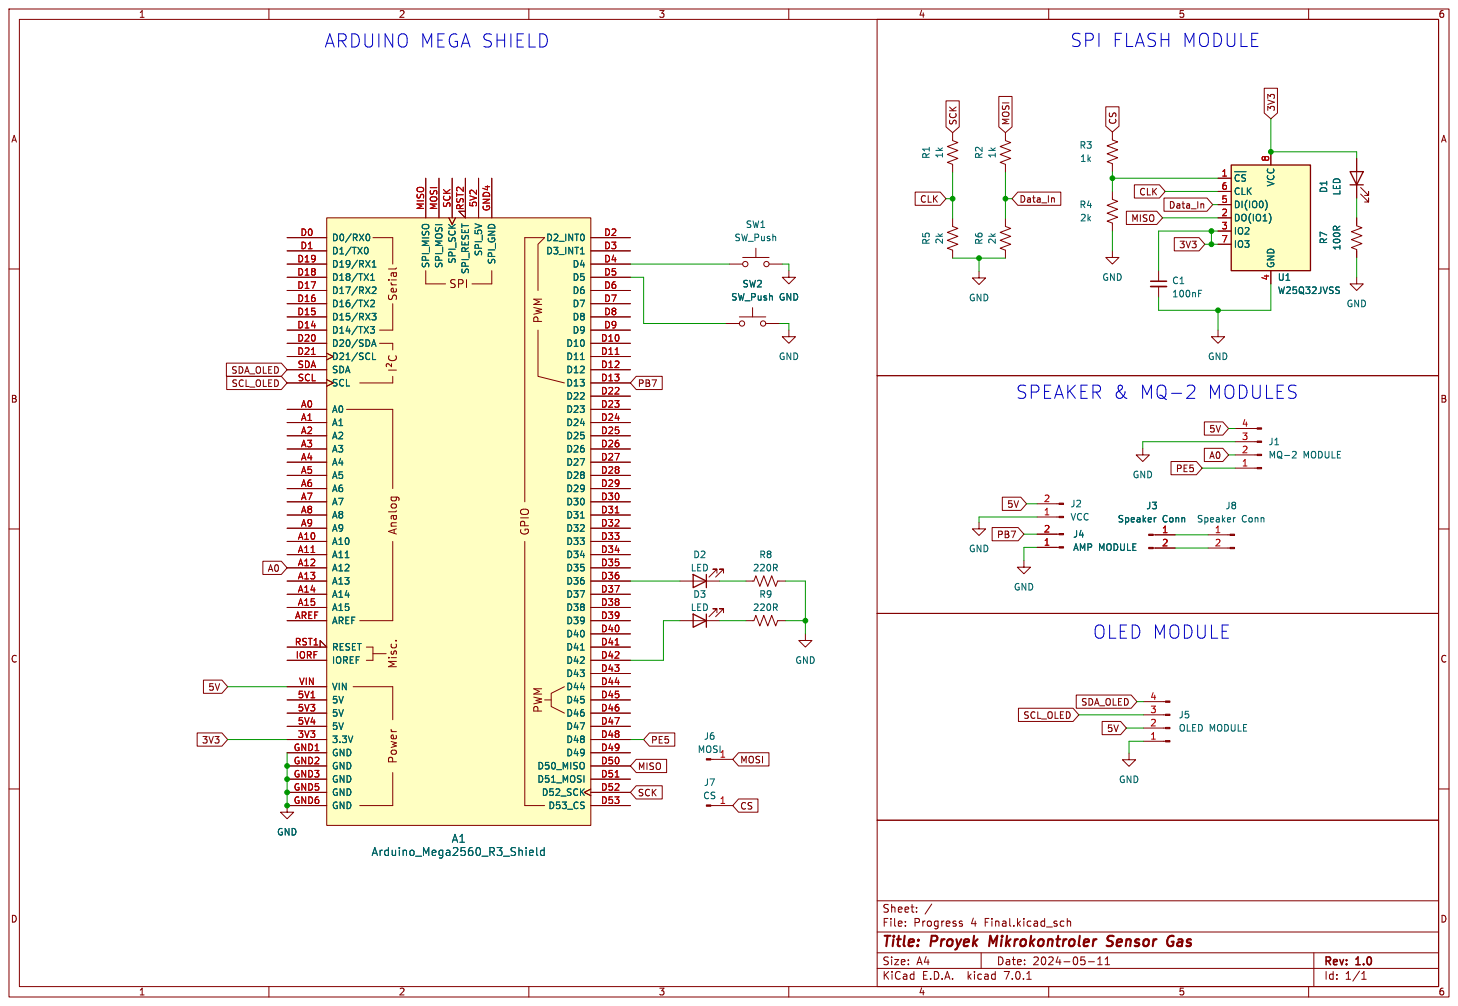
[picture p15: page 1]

Id: 1/1 Title: Proyek Mikrokontroler Sensor Gas

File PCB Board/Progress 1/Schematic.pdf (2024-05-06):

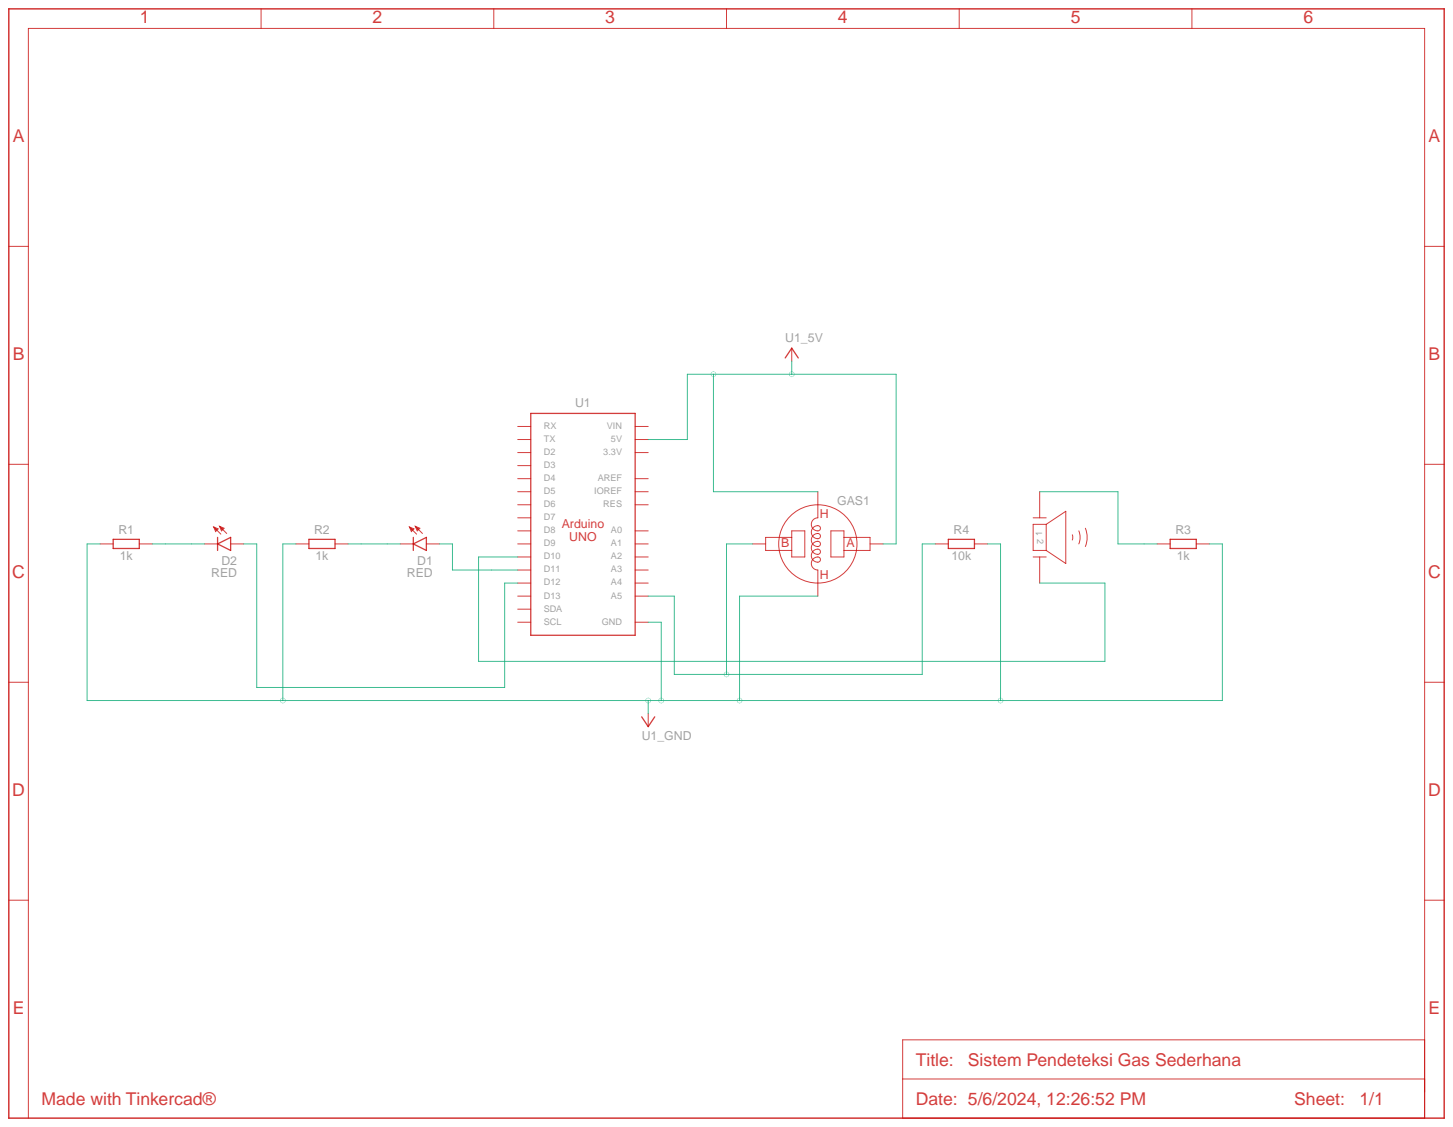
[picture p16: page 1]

Title: Sistem Pendeteksi Gas Sederhana

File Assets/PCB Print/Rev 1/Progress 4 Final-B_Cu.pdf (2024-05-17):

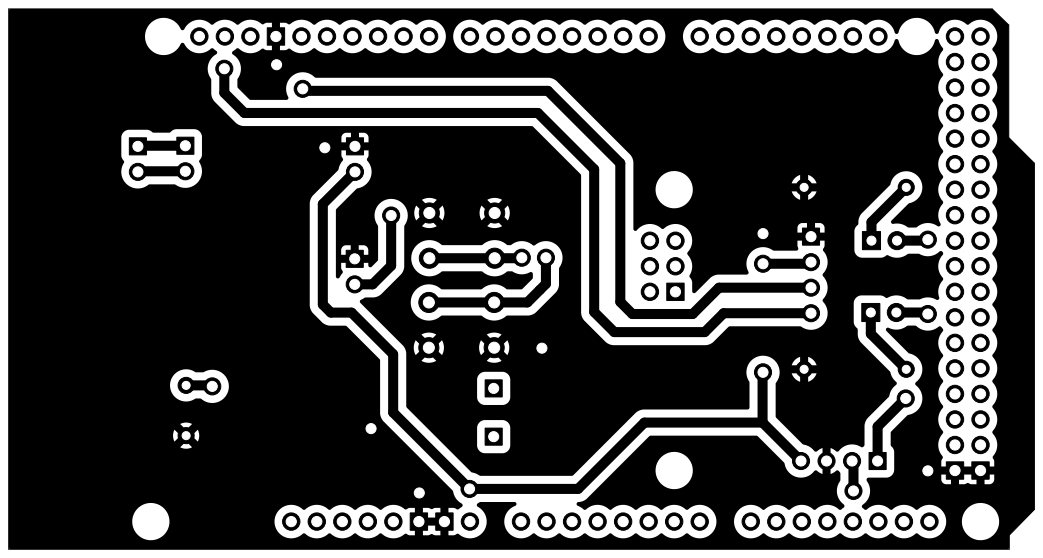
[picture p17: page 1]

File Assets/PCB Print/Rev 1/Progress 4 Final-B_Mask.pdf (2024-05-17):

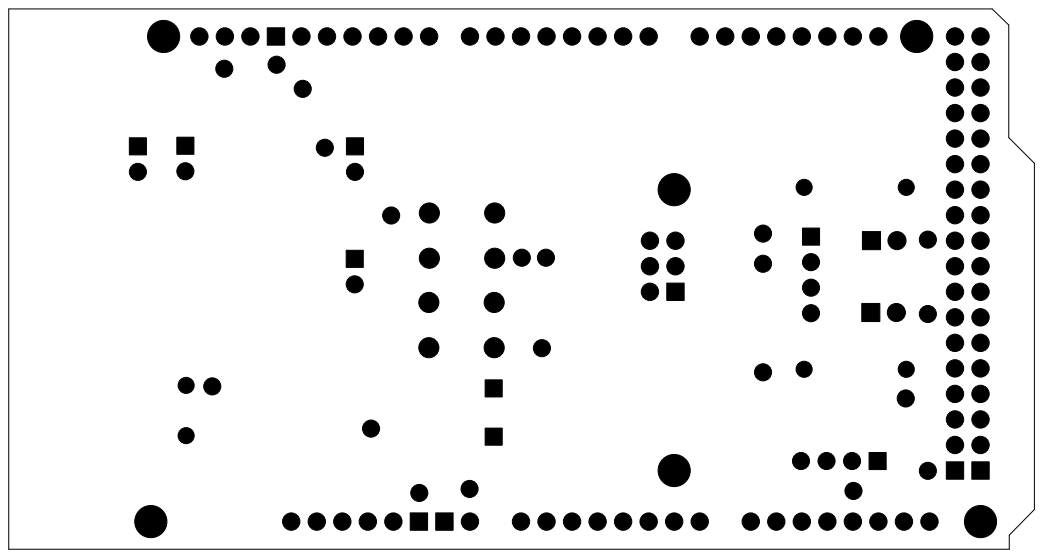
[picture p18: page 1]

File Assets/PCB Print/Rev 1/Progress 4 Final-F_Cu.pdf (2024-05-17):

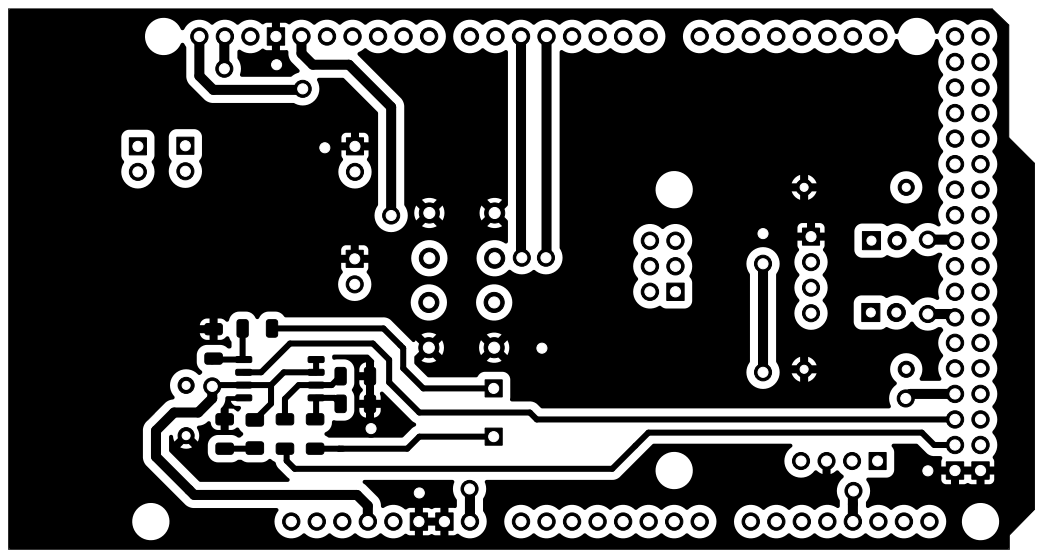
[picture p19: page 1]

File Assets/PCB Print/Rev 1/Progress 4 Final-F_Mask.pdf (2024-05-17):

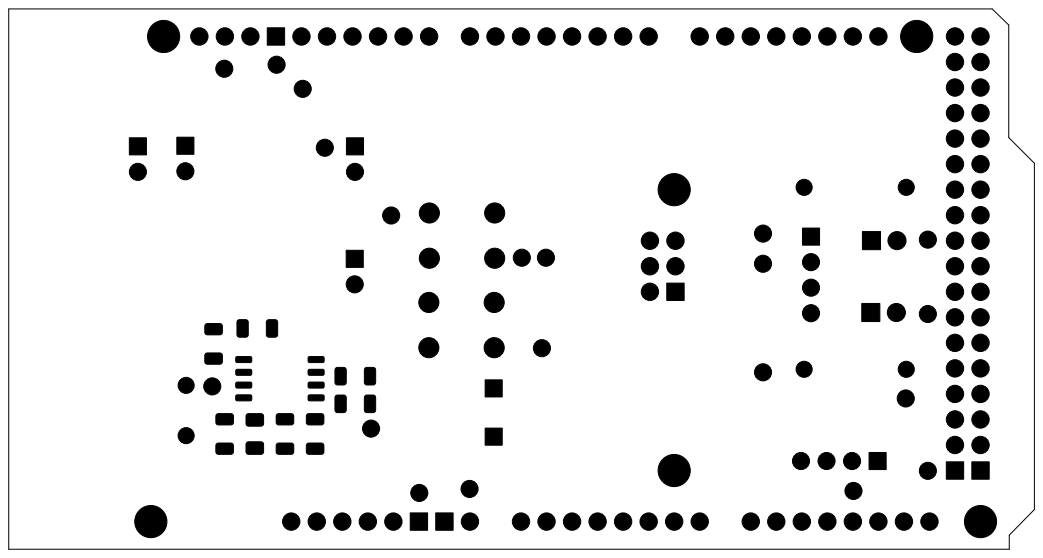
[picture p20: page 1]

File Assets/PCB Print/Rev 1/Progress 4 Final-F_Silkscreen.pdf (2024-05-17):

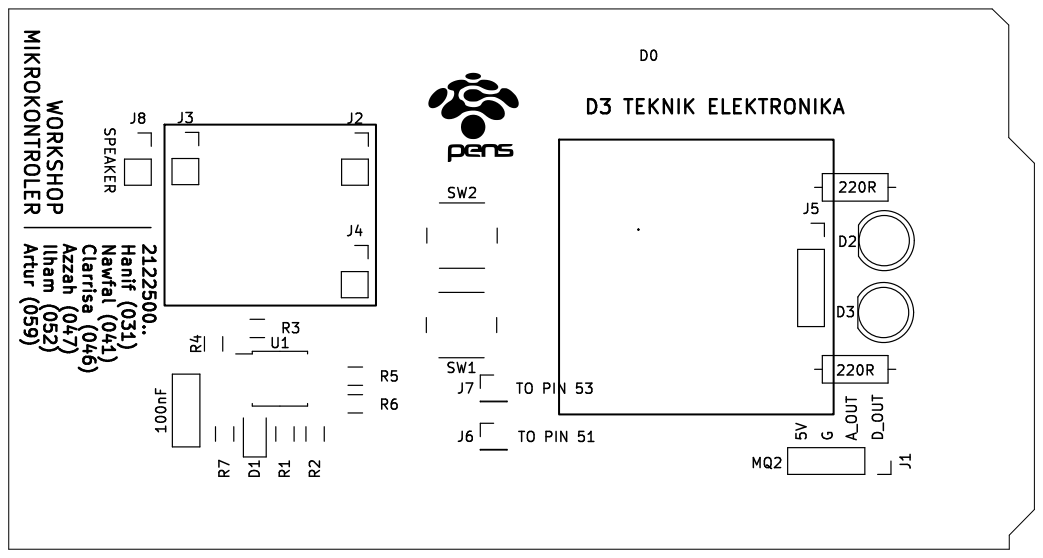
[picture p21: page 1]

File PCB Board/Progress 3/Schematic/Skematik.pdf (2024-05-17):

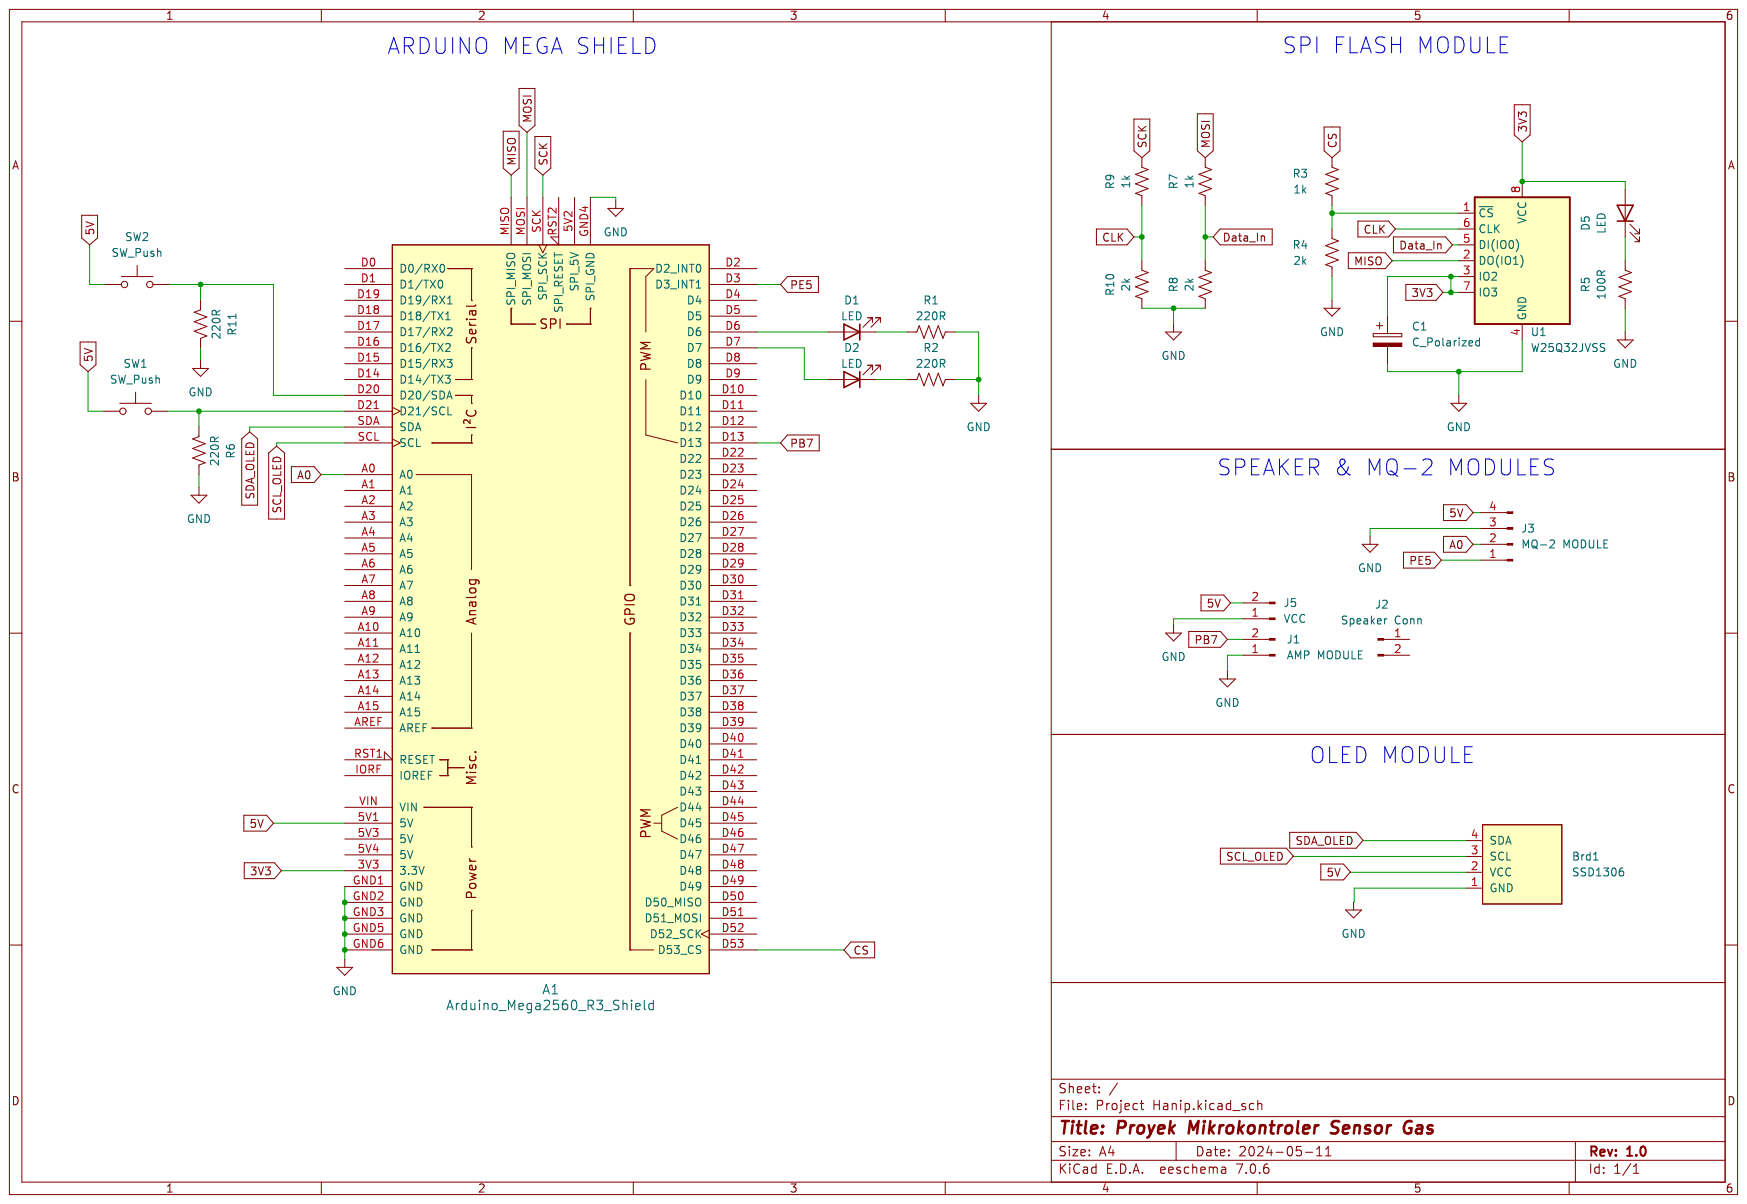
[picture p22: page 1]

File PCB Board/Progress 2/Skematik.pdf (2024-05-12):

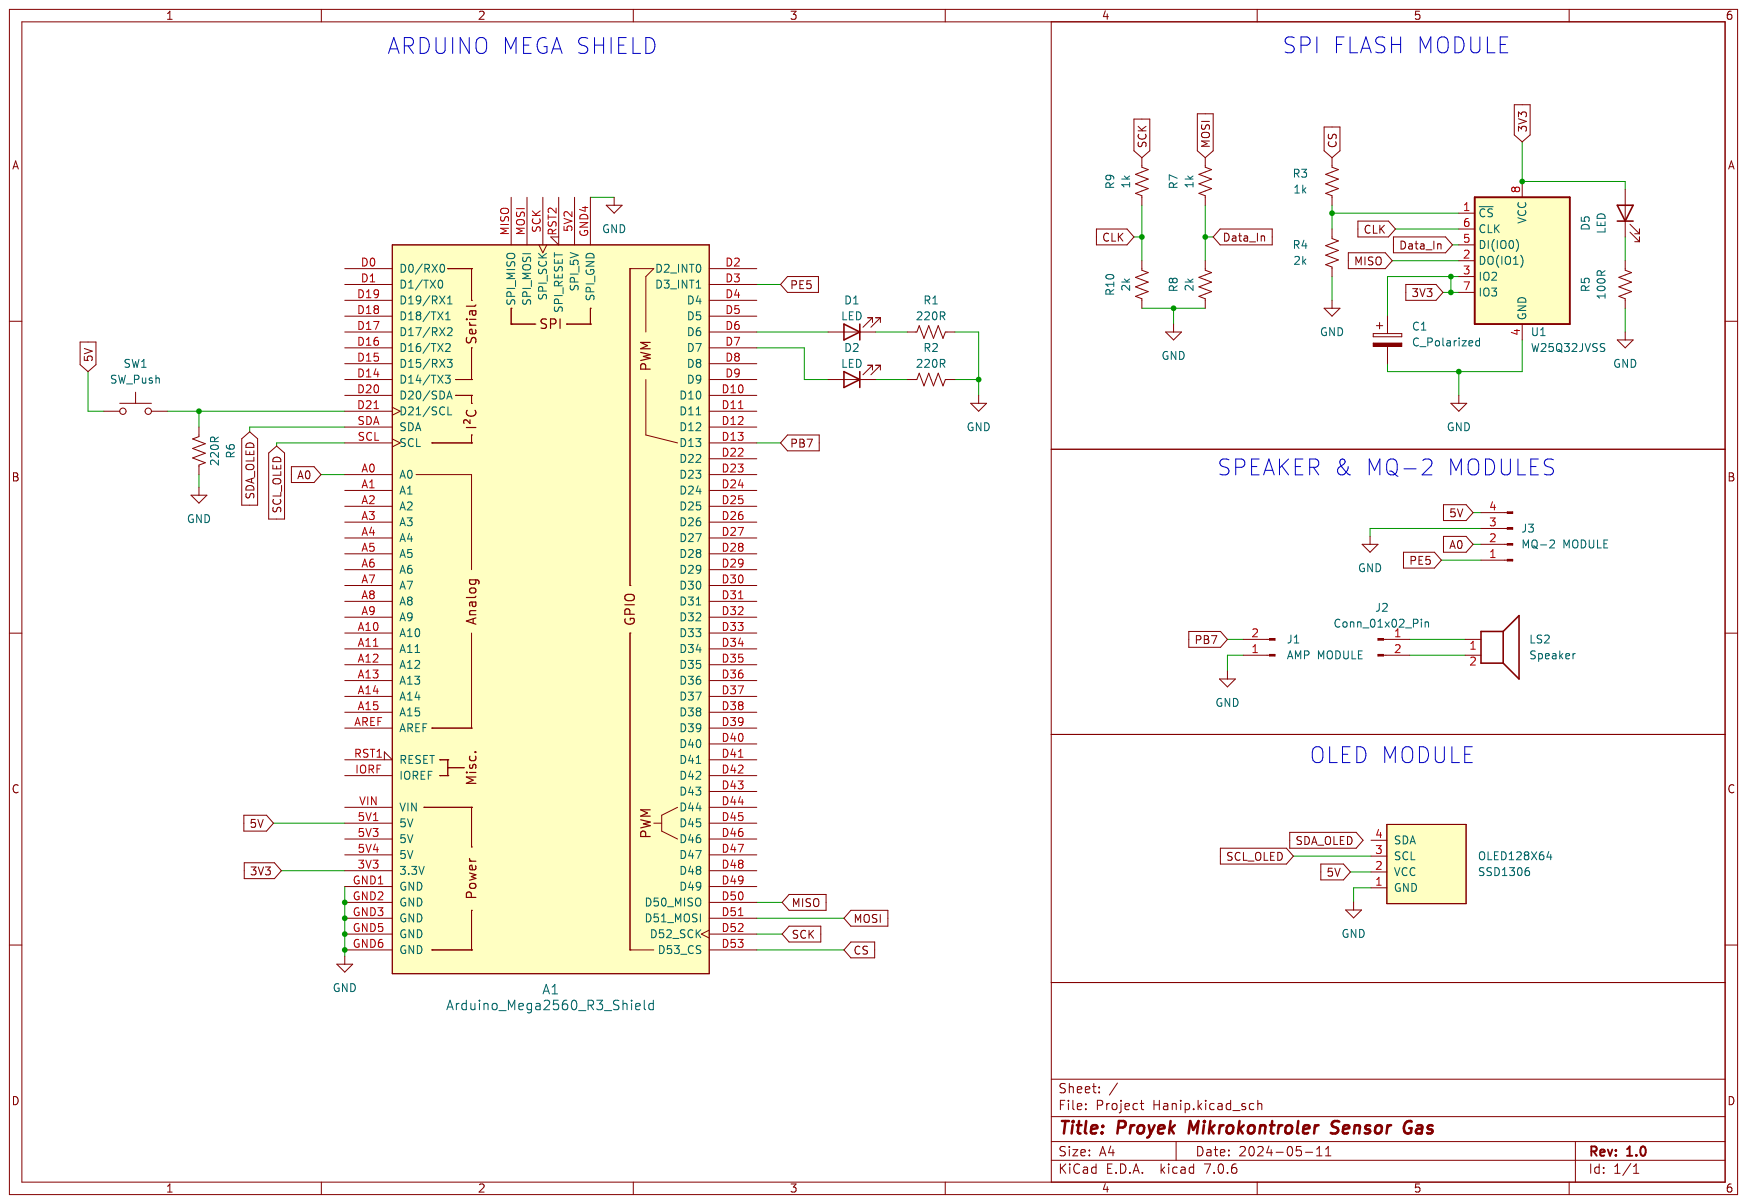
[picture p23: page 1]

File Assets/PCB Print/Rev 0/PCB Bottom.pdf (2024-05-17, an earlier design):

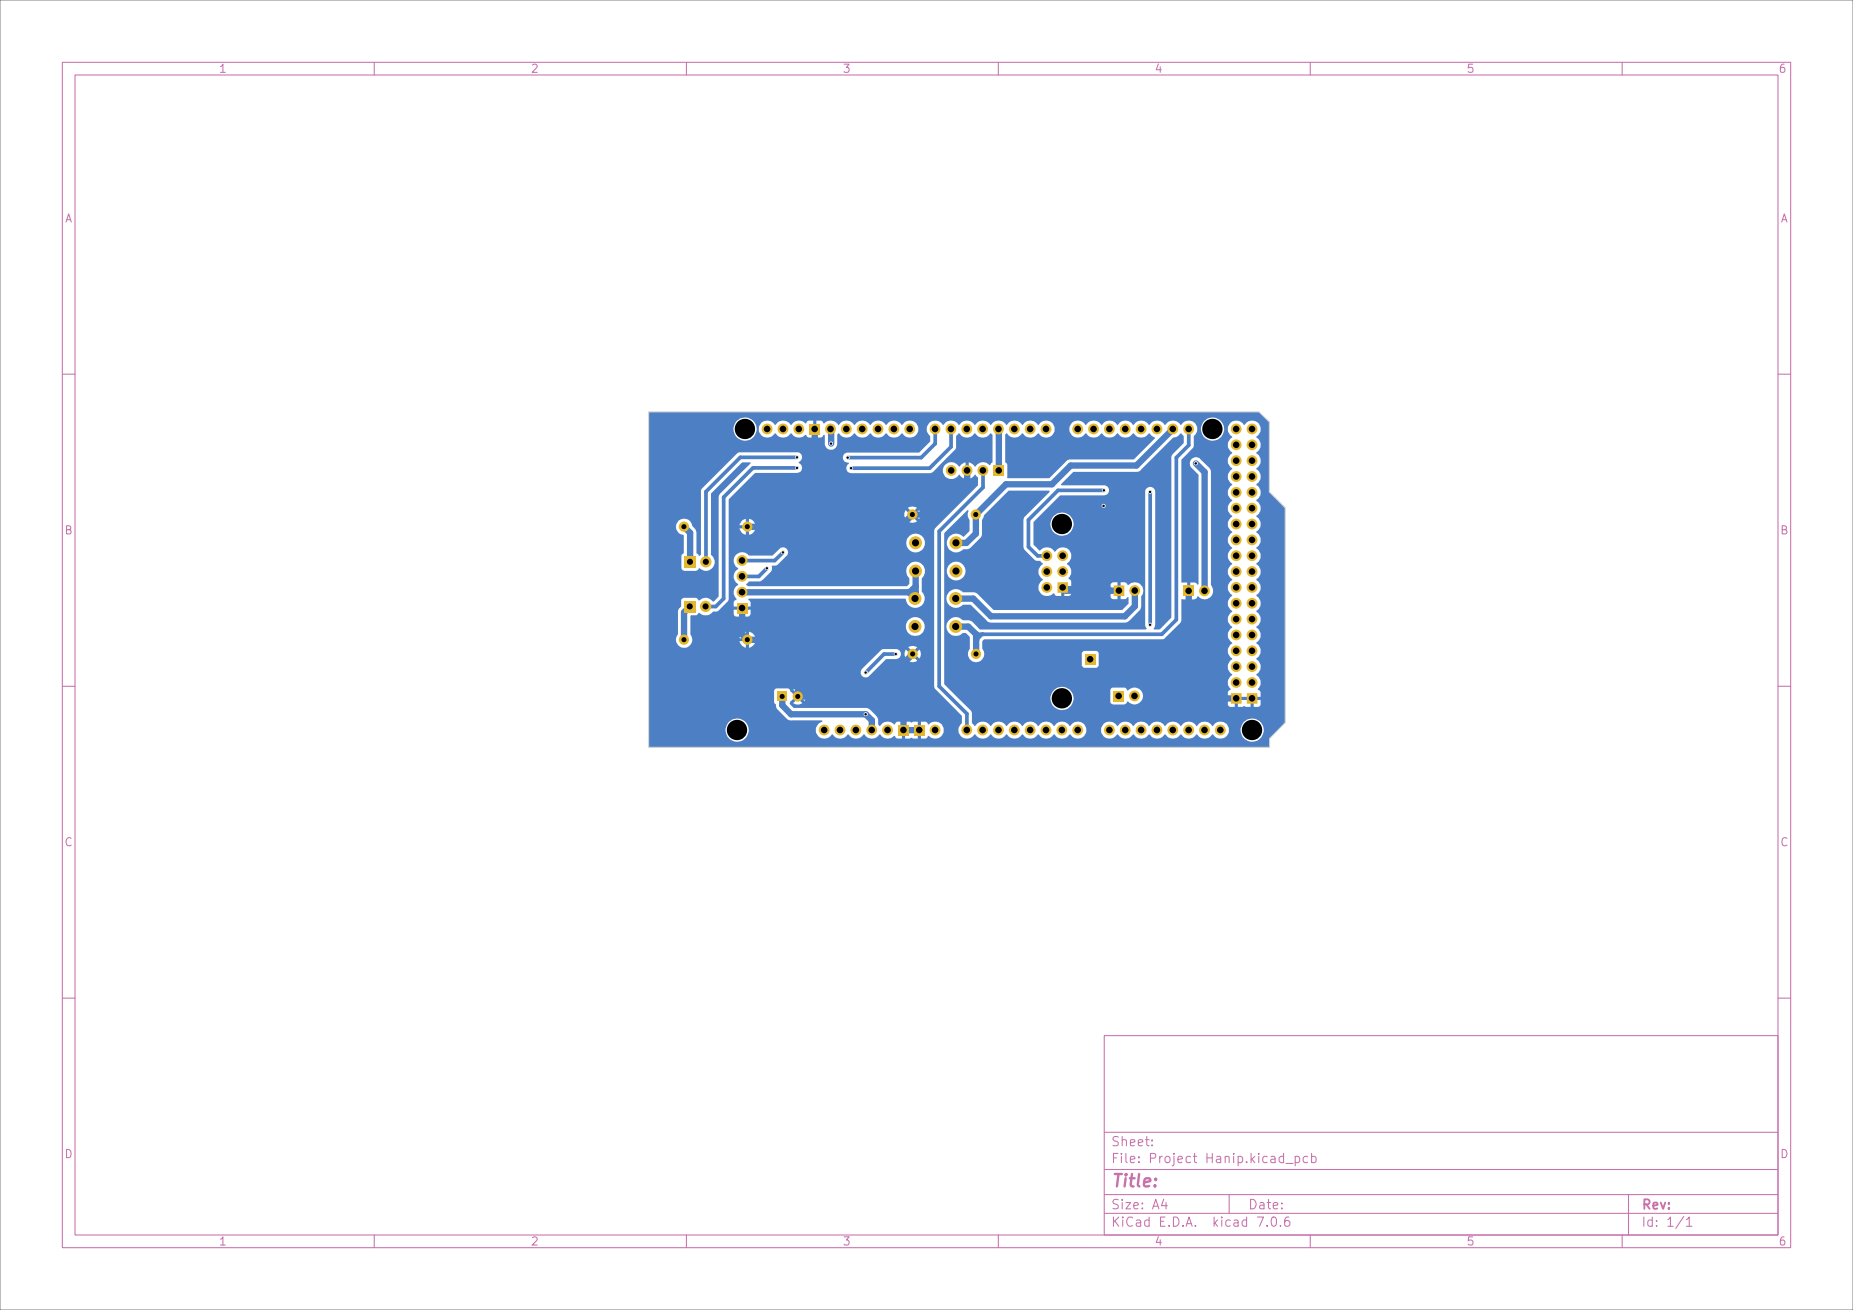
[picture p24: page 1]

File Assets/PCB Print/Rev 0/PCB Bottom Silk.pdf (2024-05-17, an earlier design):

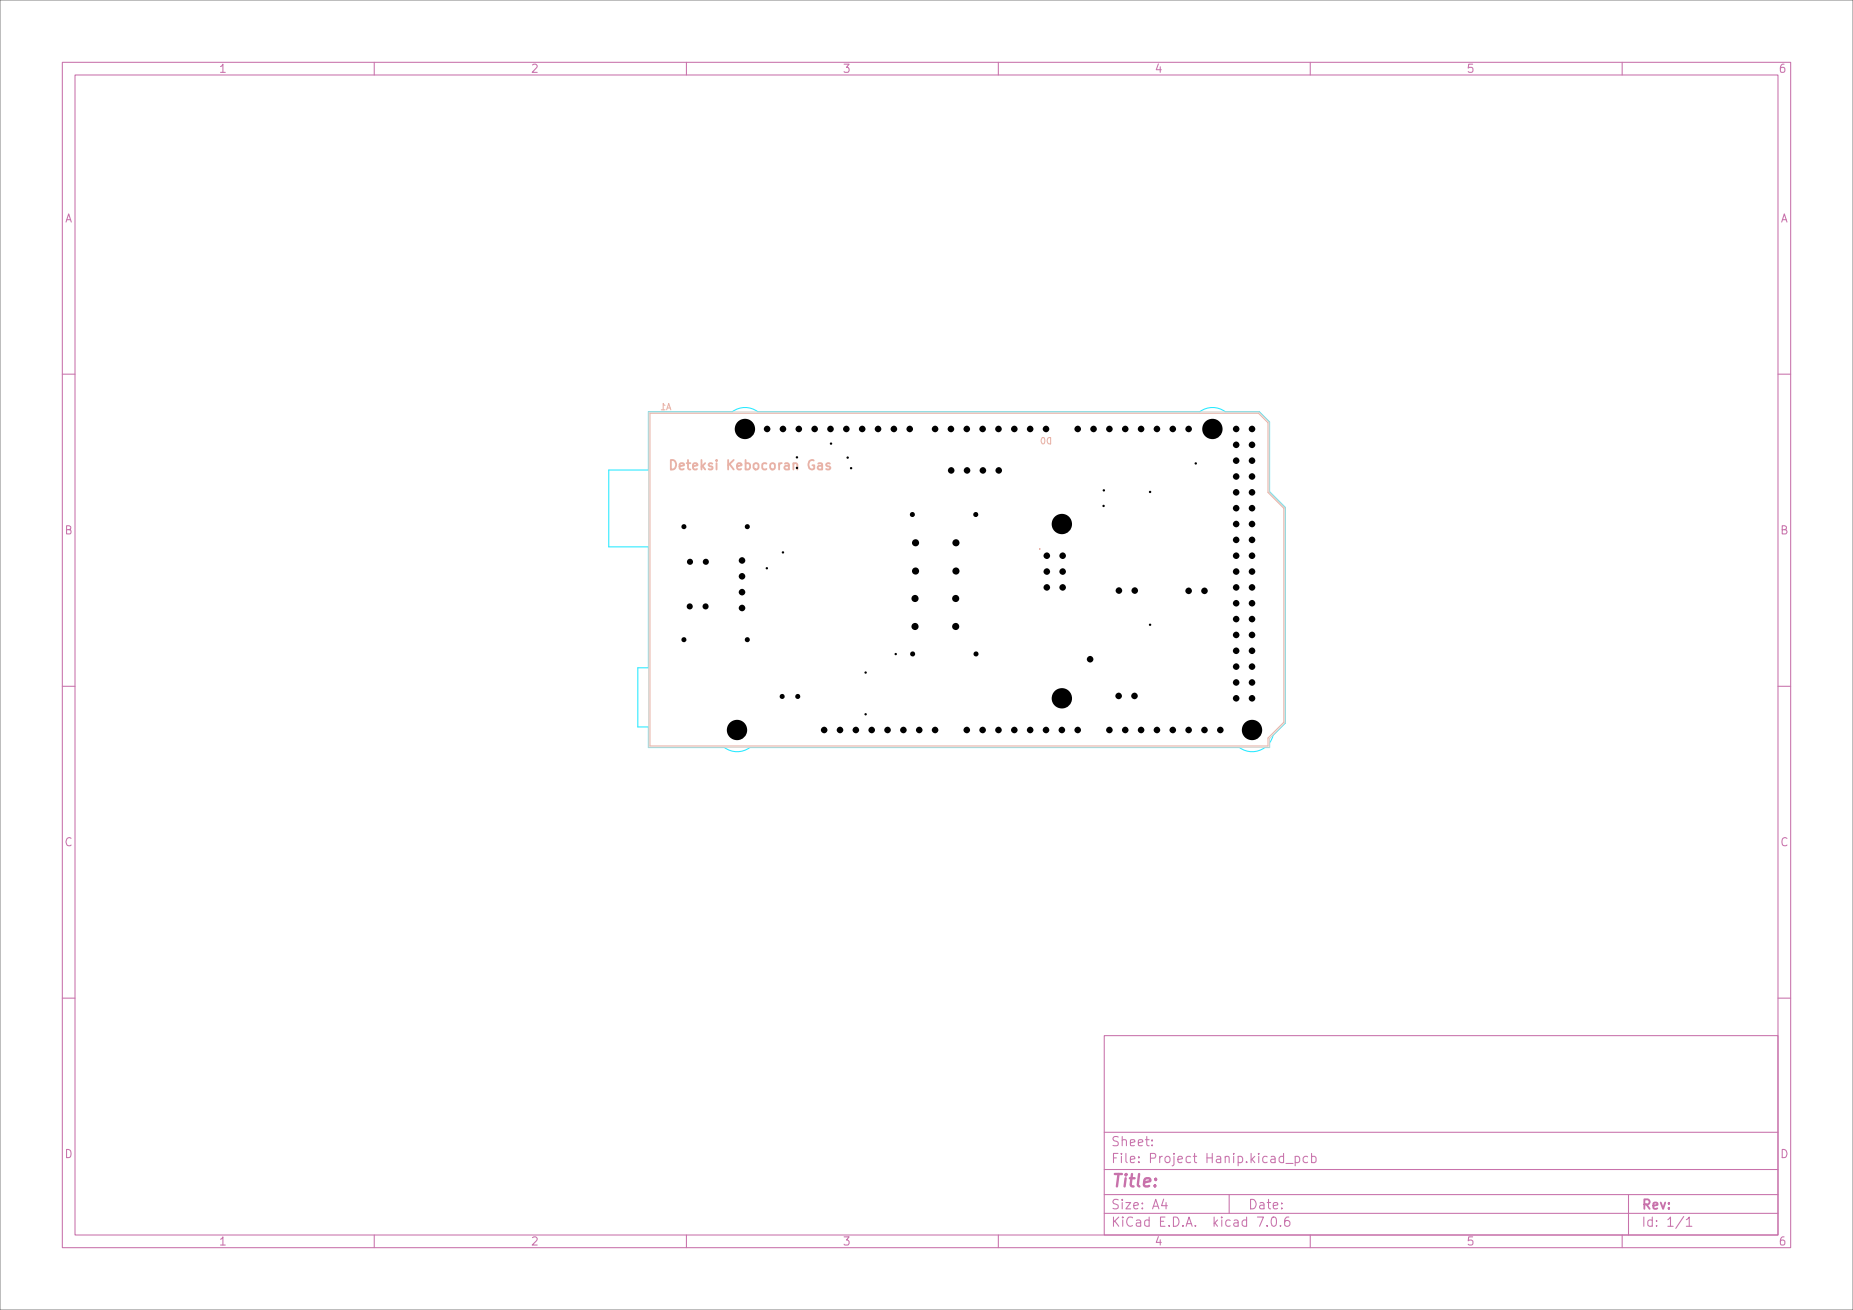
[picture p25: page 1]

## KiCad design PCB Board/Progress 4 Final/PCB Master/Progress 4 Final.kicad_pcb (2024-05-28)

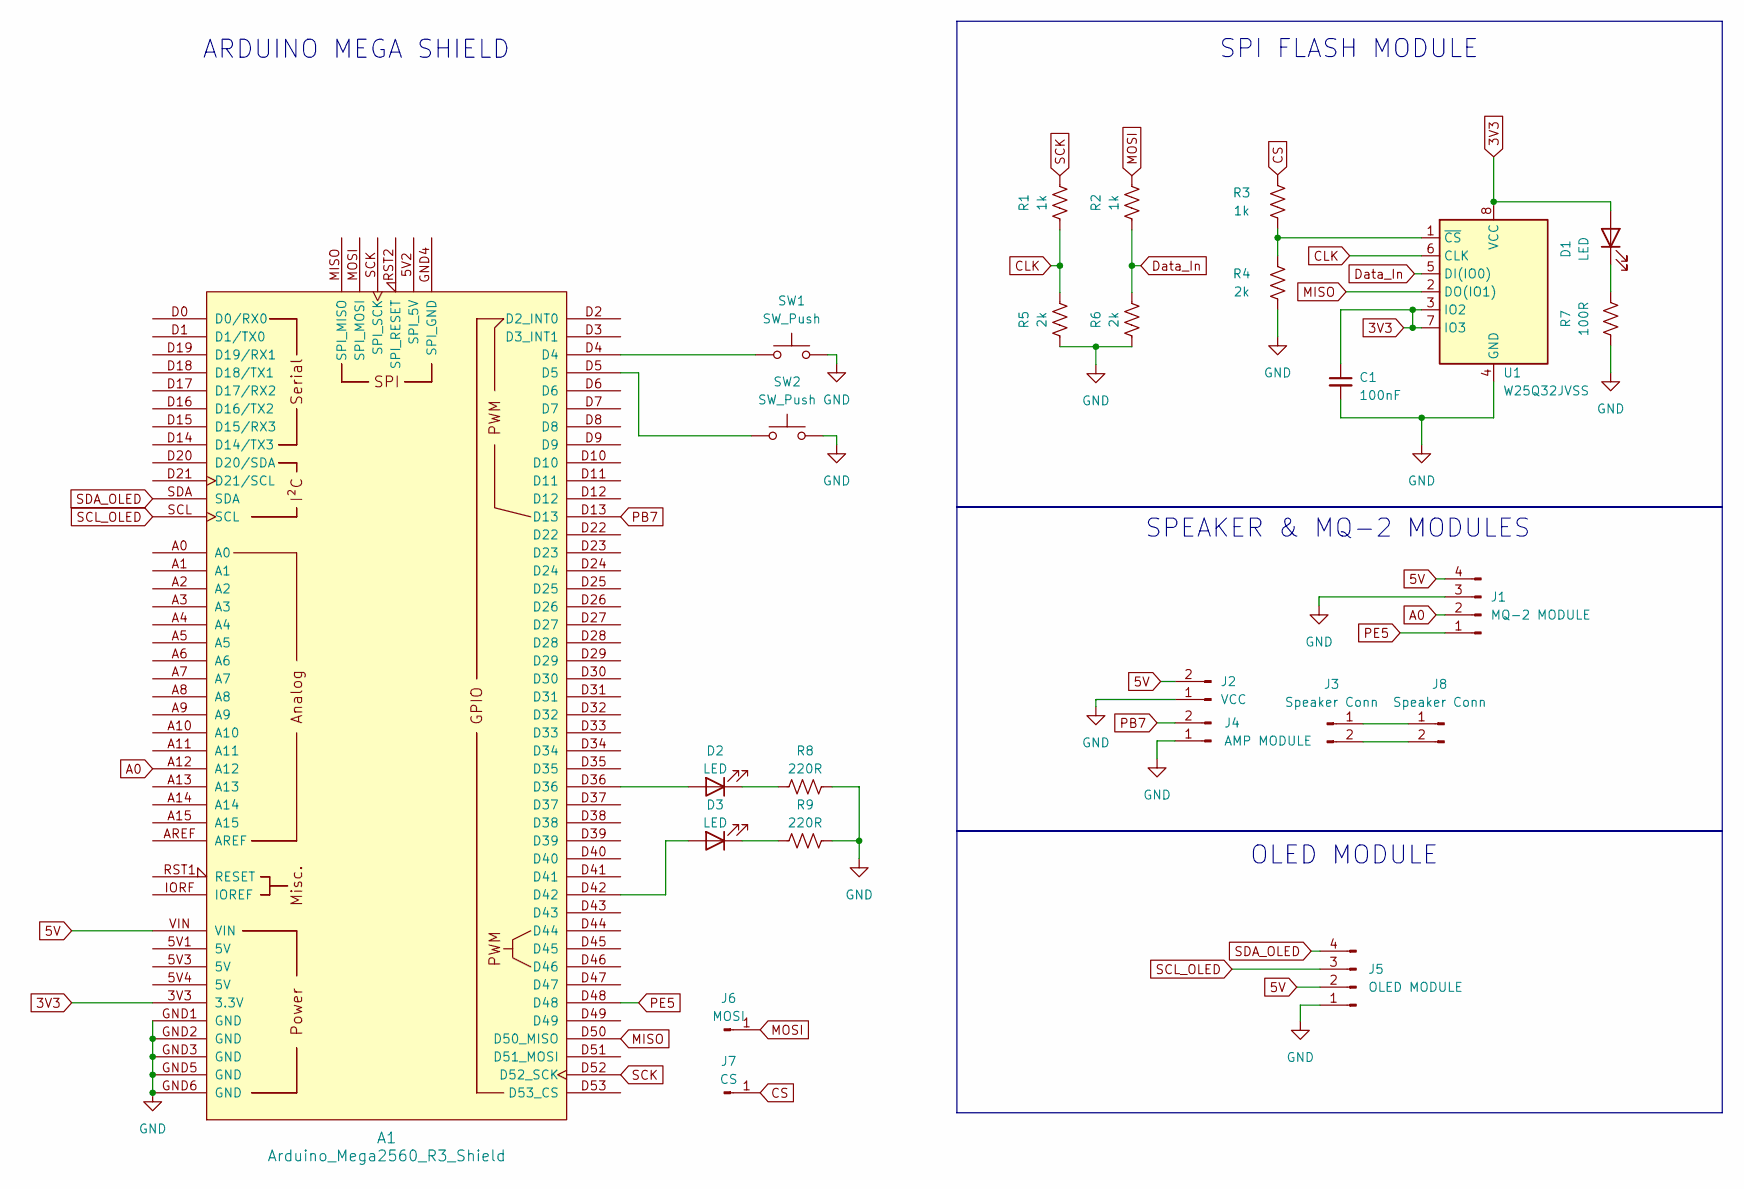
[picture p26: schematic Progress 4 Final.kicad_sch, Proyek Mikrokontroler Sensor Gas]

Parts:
A1: Arduino_Mega2560_R3_Shield
C1: 100nF; C_Rect_L7.0mm_W2.5mm_P5.00mm
D1: LED; LED_1206_3216Metric
D2, D3: LED; LED_D5.0mm
J1: MQ-2 MODULE; PinSocket_1x04_P2.54mm_Vertical
J2: VCC; PinSocket_1x02_P2.54mm_Vertical
J3, J8: Speaker Conn; PinSocket_1x02_P2.54mm_Vertical
J4: AMP MODULE; PinSocket_1x02_P2.54mm_Vertical
J5: OLED MODULE; PinSocket_1x04_P2.54mm_Vertical
J6: MOSI; PinHeader_1x01_P2.54mm_Vertical
J7: CS; PinHeader_1x01_P2.54mm_Vertical
R1, R2, R3: 1k; R_1206_3216Metric
R4, R5, R6: 2k; R_1206_3216Metric
R7: 100R; R_1206_3216Metric
R8, R9: 220R; R_Axial_DIN0207_L6.3mm_D2.5mm_P10.16mm_Horizontal
SW1, SW2: SW_Push; SW_PUSH_6mm_H8mm
U1: W25Q32JVSS; SOP-8_5.28x5.23mm_P1.27mm

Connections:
3V3: A1.3V3 (3.3V), C1.1, D1.2 (A), U1.3 (IO2), U1.7 (IO3), U1.8 (VCC)
5V: A1.VIN, J1.4, J2.2, J5.2
A0: A1.A12, J1.2
CLK: R1.2, R5.1, U1.6 (CLK)
CS: J7.1, R3.2
Data_In: R2.2, R6.1, U1.5 (DI(IO0))
GND: A1.GND1 (GND), A1.GND2 (GND), A1.GND3 (GND), A1.GND5 (GND), A1.GND6 (GND), C1.2, J1.3, J2.1, J4.1, J5.1, R4.1, R5.2, R6.2, R7.1, R8.2, R9.2, SW1.1, SW2.1, U1.4 (GND)
MISO: A1.D50 (D50_MISO), U1.2 (DO(IO1))
MOSI: J6.1, R2.1
unnamed: A1.D4, SW1.2
unnamed: A1.D5, SW2.2
unnamed: D1.1 (K), R7.2
unnamed: A1.D36, D2.2 (A)
unnamed: D2.1 (K), R8.1
unnamed: A1.D42, D3.2 (A)
unnamed: D3.1 (K), R9.1
unnamed: J3.1, J8.1
unnamed: J3.2, J8.2
unnamed: R3.1, R4.2, U1.1 (~CS)
PB7: A1.D13, J4.2
PE5: A1.D48, J1.1
SCK: A1.D52 (D52_SCK), R1.1
SCL_OLED: A1.SCL, J5.3
SDA_OLED: A1.SDA, J5.4

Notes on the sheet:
SPI FLASH MODULE
OLED MODULE
SPEAKER & MQ-2 MODULES
ARDUINO MEGA SHIELD

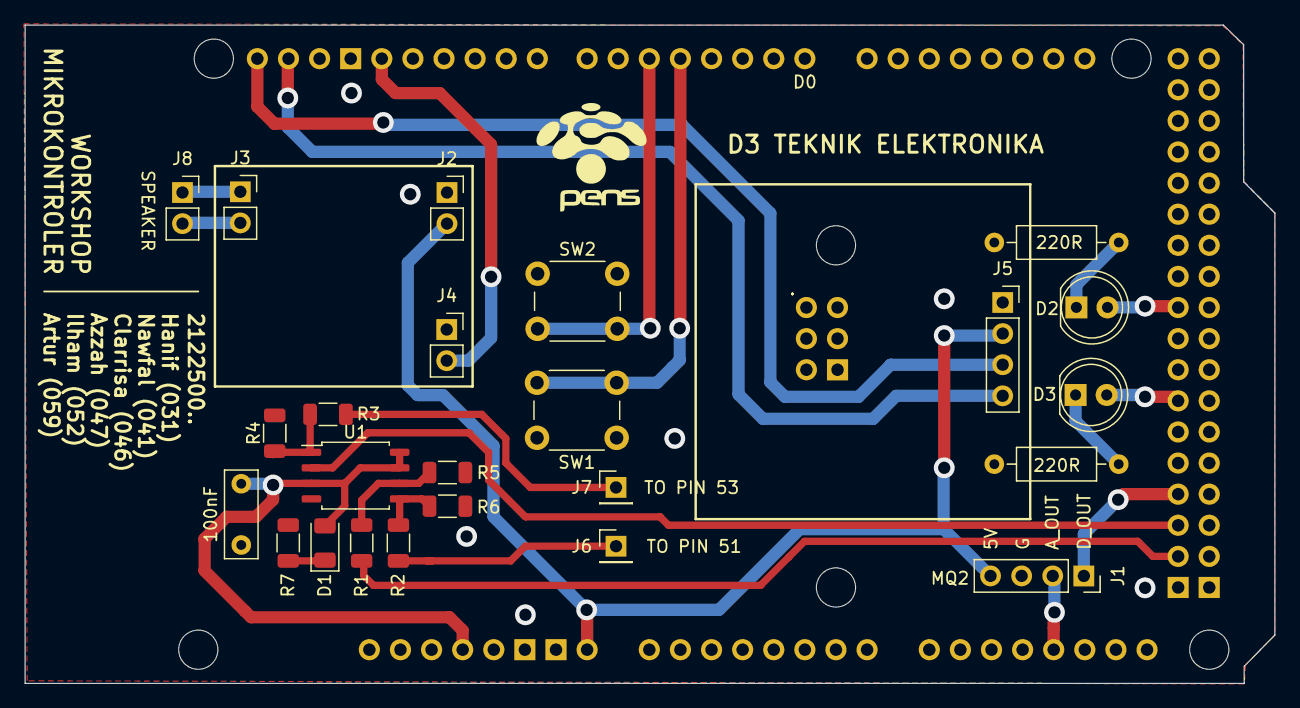
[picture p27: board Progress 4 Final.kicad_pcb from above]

Board: 2 copper layers, 102.0 x 53.8 mm, 25 parts (0 on the bottom side), 24 nets.

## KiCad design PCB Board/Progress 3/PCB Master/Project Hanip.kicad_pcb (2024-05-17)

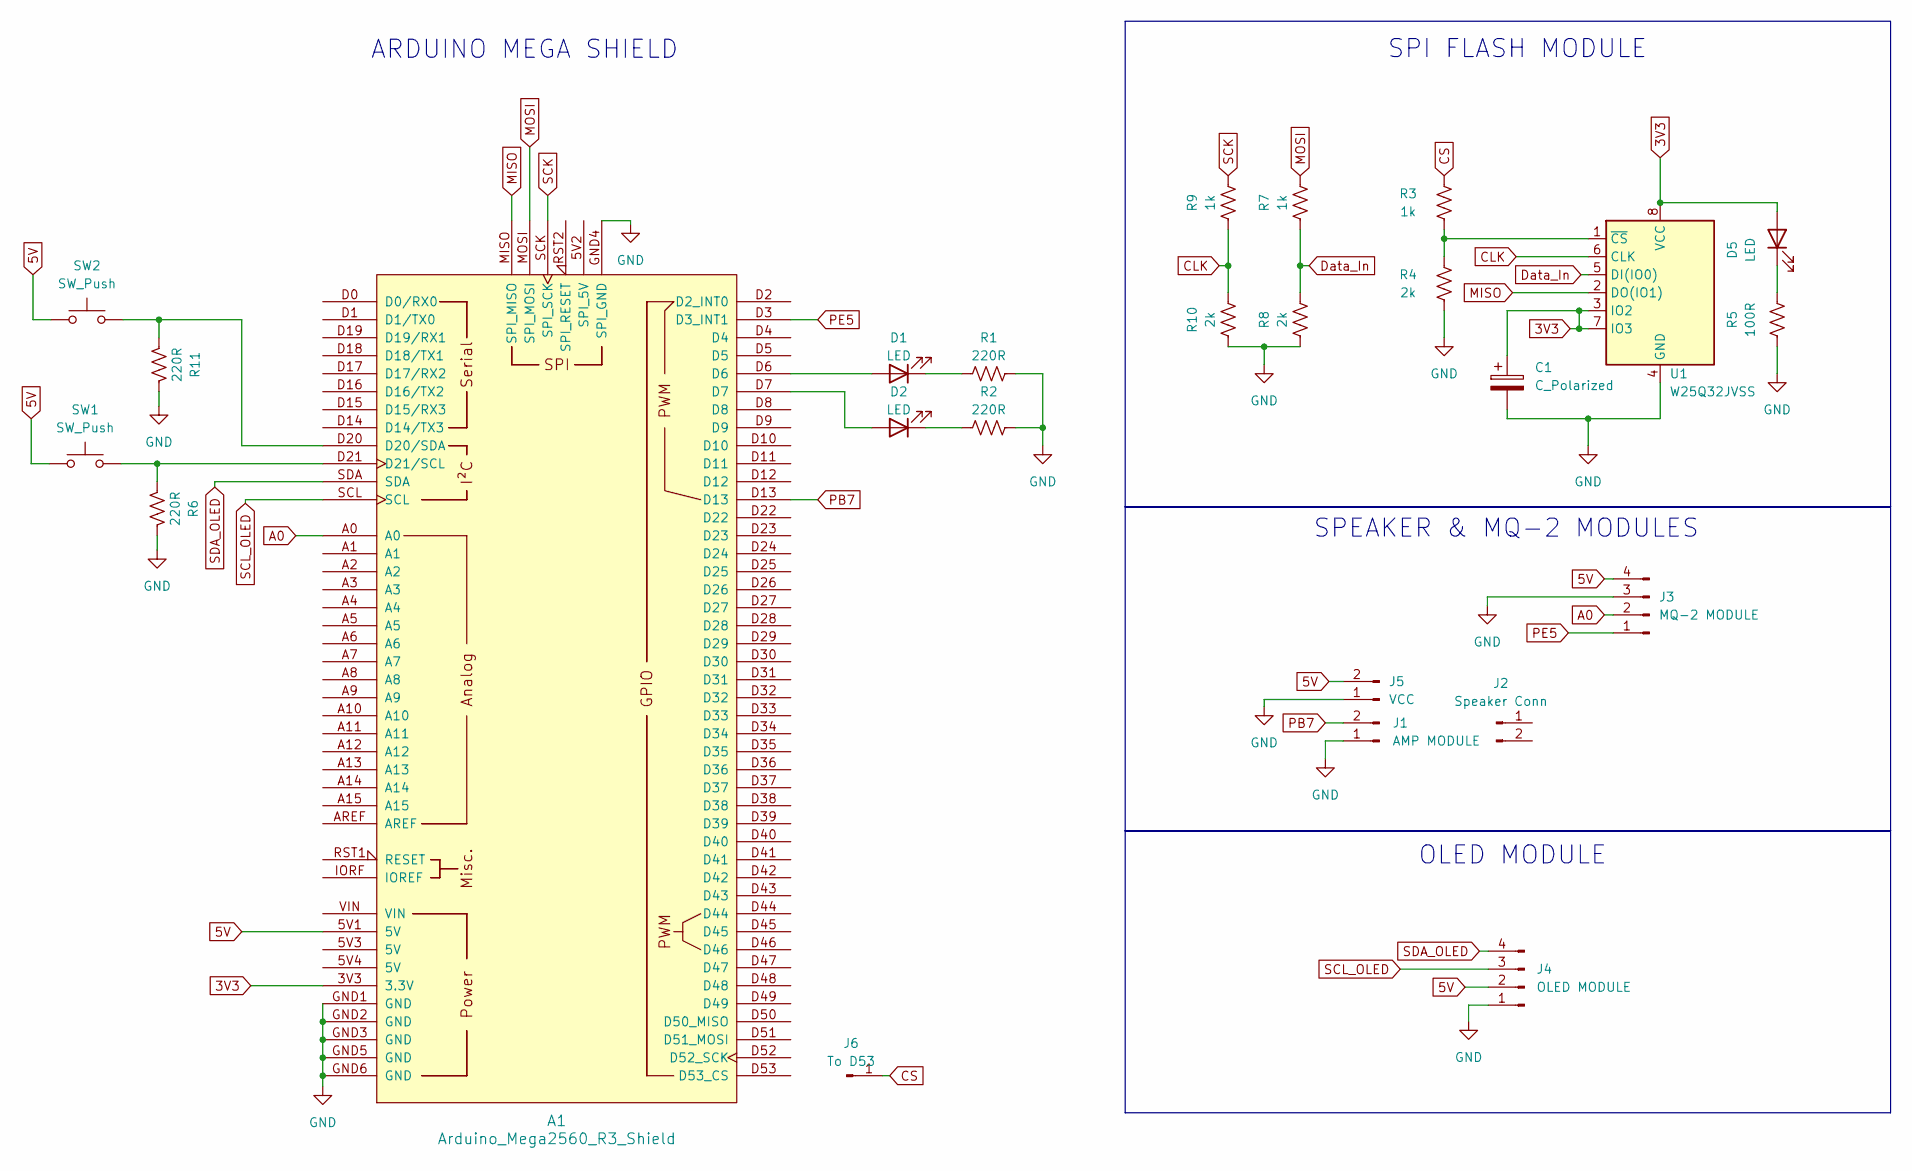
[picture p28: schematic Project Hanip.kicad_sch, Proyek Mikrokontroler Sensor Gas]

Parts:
A1: Arduino_Mega2560_R3_Shield
C1: C_Polarized; CP_Radial_D6.3mm_P2.50mm
D1, D2: LED; LED_D5.0mm
D5: LED; LED_1206_3216Metric
J1: AMP MODULE; PinSocket_1x02_P2.54mm_Vertical
J2: Speaker Conn; PinSocket_1x02_P2.54mm_Vertical
J3: MQ-2 MODULE; PinSocket_1x04_P2.54mm_Vertical
J4: OLED MODULE; PinSocket_1x04_P2.54mm_Vertical
J5: VCC; PinSocket_1x02_P2.54mm_Vertical
J6: To D53; PinSocket_1x01_P2.54mm_Vertical
R1, R2, R6, R11: 220R; R_Axial_DIN0207_L6.3mm_D2.5mm_P10.16mm_Horizontal
R3, R7, R9: 1k; R_1206_3216Metric
R4, R8, R10: 2k; R_1206_3216Metric
R5: 100R; R_1206_3216Metric
SW1, SW2: SW_Push; SW_PUSH_6mm_H8mm
U1: W25Q32JVSS; SOP-8_5.28x5.23mm_P1.27mm

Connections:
3V3: A1.3V3 (3.3V), C1.1, D5.2 (A), U1.3 (IO2), U1.7 (IO3), U1.8 (VCC)
5V: A1.5V1 (5V), J3.4, J4.2, J5.2, SW1.2, SW2.2
A0: A1.A0, J3.2
CLK: R9.2, R10.1, U1.6 (CLK)
CS: J6.1, R3.2
Data_In: R7.2, R8.1, U1.5 (DI(IO0))
GND: A1.GND1 (GND), A1.GND2 (GND), A1.GND3 (GND), A1.GND4 (SPI_GND), A1.GND5 (GND), A1.GND6 (GND), C1.2, J1.1, J3.3, J4.1, J5.1, R1.2, R2.2, R4.1, R5.1, R6.1, R8.2, R10.2, R11.1, U1.4 (GND)
MISO: A1.MISO (SPI_MISO), U1.2 (DO(IO1))
MOSI: A1.MOSI (SPI_MOSI), R7.1
unnamed: A1.D20 (D20/SDA), R11.2, SW2.1
unnamed: A1.D21 (D21/SCL), R6.2, SW1.1
unnamed: A1.D6, D1.2 (A)
unnamed: D1.1 (K), R1.1
unnamed: A1.D7, D2.2 (A)
unnamed: D2.1 (K), R2.1
unnamed: D5.1 (K), R5.2
unnamed: R3.1, R4.2, U1.1 (~CS)
PB7: A1.D13, J1.2
PE5: A1.D3 (D3_INT1), J3.1
SCK: A1.SCK (SPI_SCK), R9.1
SCL_OLED: A1.SCL, J4.3
SDA_OLED: A1.SDA, J4.4

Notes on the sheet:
SPI FLASH MODULE
OLED MODULE
SPEAKER & MQ-2 MODULES
ARDUINO MEGA SHIELD

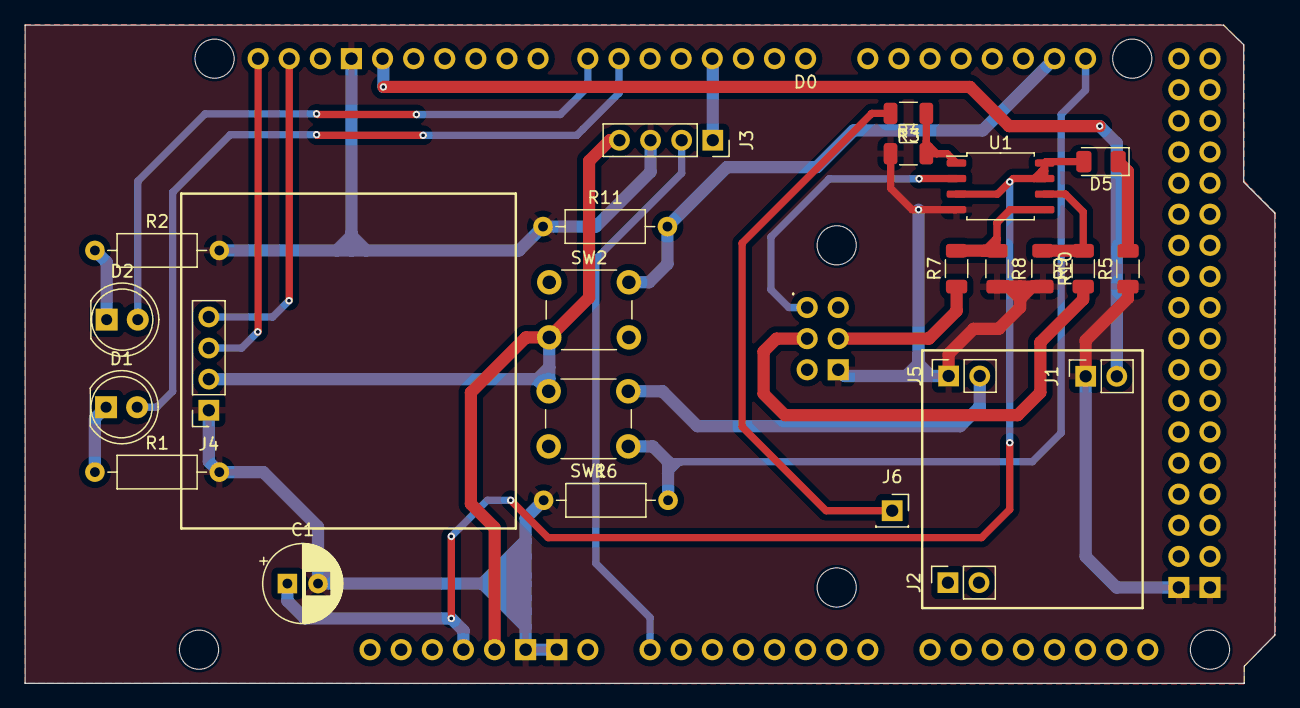
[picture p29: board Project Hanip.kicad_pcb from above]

Board: 2 copper layers, 102.0 x 53.8 mm, 25 parts (0 on the bottom side), 22 nets.

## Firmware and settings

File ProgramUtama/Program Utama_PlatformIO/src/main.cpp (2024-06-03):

#include <Arduino.h>

#include <PCMModded.h>
// Versi modifikasi dari library PCM agar dapat memutar audio
// pada pin 13 Timer 0, bukan pada bawaannya yaitu pin 10 Timer 2
// Modded by : Ilham Kurniawan

#include <EEPROM.h>

#include <Wire.h>
#include <Adafruit_SSD1306.h>
#include <Adafruit_GFX.h>

//#include <PinChangeInterrupt.h>

#include "audio1.h"
#include "audio2.h"

int redLed = 36;
int greenLed = 42;
int tombolKanan = 5;
int tombolKiri = 4;
int sensorThres[] = {600, 800, 400};
int thresholdIndex = eeprom_read_byte((uint8_t*)0);
int bacaAsap = 0;

boolean loopSound = false;

const int ButtonInt = 5;

#define OLED_RESET -1
Adafruit_SSD1306 display(OLED_RESET);

//===========================================================================

void ISR1() {
  stopPlayback();
  delay(3000);
}

boolean playing(void)
{
  return TIMSK1 & _BV(OCIE1A);
}

void putarSuara() {
  loopSound = true;
  while (loopSound) {
    
    if (digitalRead(tombolKanan) == 0) {
      loopSound = false;
      return;
    }

    int pilihanLagu = eeprom_read_byte((uint8_t*)0);
    if (pilihanLagu == 1) {
      startPlayback(audio2, sizeof(audio2));
    }
    else {
      startPlayback(audio1, sizeof(audio1));
    }
    
    while (playing());
  }
}

void ThresholdCheck() {
  if (digitalRead(tombolKiri) == 0) {
    delay(500);
    thresholdIndex++;
    if (thresholdIndex == 3) {
      thresholdIndex = 0;
    }
    eeprom_write_byte((uint8_t*)0, thresholdIndex);
  }
  return;
}

// ===============================================================================

void setup() {
  pinMode(redLed, OUTPUT);
  pinMode(greenLed, OUTPUT);

  pinMode(ButtonInt, INPUT);
  //attachInterrupt(digitalPinToInterrupt(ButtonInt), ISR1, CHANGE);

  pinMode(A12, INPUT);

  pinMode(tombolKanan, INPUT_PULLUP);
  pinMode(tombolKiri, INPUT_PULLUP);

  display.begin(SSD1306_SWITCHCAPVCC, 0x3C);
  display.clearDisplay();
  display.display();

  Serial.begin(9600);
}

void loop() {
  bacaAsap = analogRead(A12);
  ThresholdCheck();

  Serial.print("Pin A0: ");
  Serial.println(bacaAsap);

  display.clearDisplay();
  display.setTextSize(1);
  display.setTextColor(SSD1306_WHITE);
  display.setCursor(50, 10);
  display.print(bacaAsap);
  display.setCursor(0, 0);
  display.print("Threshold = ");
  display.setCursor(70, 0);
  display.print(sensorThres[thresholdIndex]);
  display.display();


  if (bacaAsap > sensorThres[thresholdIndex])
  {
    digitalWrite(redLed, HIGH);
    digitalWrite(greenLed, LOW);

    putarSuara();
    //startPlayback(audio1, sizeof(audio1));
    //while (playing());
    
  }
  else
  {
    digitalWrite(redLed, LOW);
    digitalWrite(greenLed, HIGH);
  }

  delay(300);
}

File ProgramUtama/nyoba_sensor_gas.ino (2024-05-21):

#include "PCM.h"
const unsigned char sample [] PROGMEM = {
      126, 126, 126, 126, 127, 128, 128, 128, 128, 129, 129, 130, 130, 130, 131, 130, 128, 126, 124, 124, 124, 125, 126, 125, 125, 124, 125, 126, 125, 127, 130, 131, 133, 133, 132, 128, 126, 125, 126, 128, 128, 129, 129, 125, 125, 126, 125, 126, 127, 132, 138, 137, 135, 133, 133, 133, 131, 131, 130, 130, 128, 122, 123, 121, 120, 123, 122, 127, 131, 128, 127, 124, 121, 122, 125, 127, 126, 125, 123, 121, 120, 116, 118, 120, 124, 132, 136, 136, 135, 135, 138, 137, 137, 137, 138, 135, 129, 126, 124, 122, 121, 120, 121, 127, 128, 127, 125, 124, 125, 127, 128, 130, 132, 131, 129, 130, 128, 122, 120, 121, 124, 125, 123, 124, 126, 126, 126, 127, 132, 135, 137, 137, 136, 138, 134, 129, 127, 124, 127, 127, 124, 123, 120, 118, 120, 120, 122, 127, 130, 131, 131, 130, 128, 127, 128, 128, 129, 130, 128, 127, 127, 124, 120, 121, 124, 125, 126, 128, 131, 132, 129, 126, 128, 130, 132, 133, 131, 129, 128, 128, 128, 128, 128, 130, 134, 134, 131, 129, 127, 127, 127, 126, 126, 129, 132, 130, 127, 124, 123, 125, 124, 120, 121, 123, 123, 121, 120, 122, 127, 129, 128, 131, 132, 130, 131, 130, 128, 130, 128, 127, 132, 131, 129, 128, 126, 127, 129, 127, 127, 130, 130, 128, 127, 124, 125, 128, 124, 124, 127, 127, 125, 122, 121, 123, 125, 124, 124, 128, 131, 131, 131, 128, 130, 131, 129, 132, 133, 132, 132, 130, 127, 130, 129, 126, 128, 130, 129, 127, 124, 123, 126, 124, 123, 125, 129, 132, 128, 125, 129, 129, 126, 125, 127, 131, 132, 127, 126, 129, 130, 127, 126, 127, 131, 131, 126, 127, 130, 131, 128, 127, 131, 134, 132, 129, 127, 129, 128, 125, 125, 126, 126, 125, 121, 120, 122, 119, 121, 124, 126, 127, 130, 130, 131, 134, 128, 131, 133, 131, 129, 129, 127, 127, 124, 121, 124, 126, 128, 130, 131, 130, 134, 129, 129, 131, 129, 127, 129, 128, 125, 126, 119, 118, 123, 120, 117, 122, 124, 123, 127, 128, 128, 133, 132, 130, 135, 133, 129, 129, 128, 125, 128, 126, 125, 133, 129, 129, 132, 131, 131, 134, 131, 133, 137, 133, 131, 128, 125, 125, 124, 118, 124, 123, 117, 121, 120, 119, 122, 124, 125, 133, 135, 133, 134, 133, 130, 127, 125, 123, 126, 124, 123, 128, 125, 124, 128, 129, 129, 133, 134, 134, 136, 133, 132, 133, 130, 126, 125, 123, 124, 118, 116, 121, 120, 119, 122, 124, 128, 131, 130, 130, 134, 134, 131, 131, 132, 131, 128, 123, 122, 125, 123, 122, 124, 130, 132, 129, 129, 130, 134, 134, 131, 132, 134, 132, 128, 127, 125, 124, 124, 122, 122, 123, 123, 123, 125, 125, 126, 127, 129, 132, 131, 131, 131, 131, 128, 126, 125, 126, 126, 127, 126, 127, 126, 126, 126, 127, 129, 126, 129, 129, 127, 128, 130, 125, 127, 130, 126, 129, 129, 129, 130, 130, 129, 132, 129, 126, 132, 128, 127, 130, 128, 127, 128, 126, 129, 130, 125, 127, 128, 126, 128, 128, 128, 131, 130, 127, 127, 125, 124, 127, 122, 122, 127, 125, 125, 127, 126, 126, 129, 127, 131, 129, 127, 131, 130, 126, 126, 127, 126, 126, 125, 127, 126, 125, 128, 127, 125, 130, 130, 129, 132, 130, 131, 132, 128, 128, 129, 124, 127, 127, 124, 126, 126, 124, 124, 124, 126, 129, 128, 129, 130, 128, 129, 129, 128, 128, 128, 128, 129, 126, 127, 128, 125, 126, 129, 128, 129, 130, 128, 131, 129, 127, 128, 129, 125, 126, 129, 127, 125, 126, 128, 126, 126, 127, 127, 127, 128, 126, 125, 126, 127, 128, 127, 126, 130, 129, 127, 127, 128, 129, 128, 128, 127, 127, 128, 129, 129, 129, 130, 130, 128, 128, 127, 126, 126, 127, 126, 126, 127, 128, 129, 131, 129, 127, 130, 128, 125, 129, 129, 127, 128, 128, 128, 127, 127, 126, 126, 125, 123, 127, 125, 124, 126, 127, 127, 127, 129, 127, 128, 129, 127, 126, 126, 127, 128, 129, 129, 132, 132, 130, 129, 129, 128, 127, 126, 126, 126, 125, 125, 126, 126, 126, 128, 128, 131, 131, 131, 132, 130, 130, 130, 128, 127, 127, 125, 122, 121, 123, 124, 125, 127, 129, 130, 130, 130, 129, 129, 129, 130, 131, 131, 128, 129, 128, 126, 125, 124, 125, 125, 125, 126, 126, 129, 130, 129, 129, 129, 130, 128, 128, 127, 128, 129, 127, 126, 125, 124, 123, 124, 126, 126, 129, 131, 129, 127, 126, 125, 126, 127, 127, 131, 133, 133, 131, 130, 127, 124, 126, 125, 124, 126, 126, 126, 127, 127, 127, 129, 128, 127, 128, 128, 128, 128, 128, 130, 130, 129, 127, 128, 127, 126, 126, 127, 127, 127, 128, 127, 126, 126, 127, 128, 128, 130, 128, 128, 129, 128, 126, 127, 127, 127, 126, 125, 126, 127, 126, 125, 126, 126, 126, 127, 127, 130, 131, 130, 130, 130, 129, 128, 127, 127, 127, 128, 128, 127, 127, 126, 124, 125, 126, 127, 129, 131, 132, 132, 131, 129, 128, 127, 125, 125, 125, 126, 126, 127, 126, 126, 126, 125, 125, 125, 127, 129, 131, 131, 131, 129, 128, 126, 125, 126, 126, 127, 128, 129, 128, 127, 126, 127, 127, 128, 129, 131, 131, 130, 129, 128, 126, 125, 125, 126, 126, 127, 128, 128, 128, 128, 128, 127, 128, 129, 128, 128, 128, 129, 128, 128, 127, 128, 127, 126, 126, 126, 128, 127, 128, 129, 130, 129, 129, 129, 129, 128, 128, 129, 128, 127, 125, 126, 125, 124, 125, 127, 127, 129, 129, 129, 128, 127, 127, 127, 126, 125, 128, 128, 128, 128, 129, 128, 127, 127, 128, 127, 127, 129, 130, 129, 128, 128, 127, 126, 125, 125, 126, 127, 126, 128, 128, 127, 127, 126, 127, 128, 128, 128, 129, 129, 129, 127, 128, 128, 127, 127, 128, 129, 129, 128, 129, 129, 128, 128, 129, 129, 128, 128, 128, 127, 126, 126, 126, 126, 126, 126, 127, 127, 127, 127, 127, 127, 126, 127, 128, 127, 128, 129, 129, 128, 128, 128, 127, 126, 125, 127, 127, 127, 129, 129, 129, 130, 129, 128, 128, 128, 127, 127, 127, 127, 127, 126, 126, 126, 126, 126, 126, 126, 126, 128, 127, 127, 128, 130, 130, 129, 129, 130, 129, 128, 128, 128, 127, 127, 127, 128, 128, 128, 129, 129, 129, 128, 128, 127, 127, 126, 127, 127, 126, 126, 127, 127, 127, 127, 127, 127, 127, 127, 126, 127, 127, 127, 127, 127, 127, 128, 127, 127, 128, 128, 128, 128, 128, 128, 128, 128, 128, 128, 128, 129, 128, 128, 128, 128, 127, 127, 127, 127, 126, 126, 127, 127, 127, 127, 128, 128, 127, 127, 127, 127, 127, 127, 128, 128, 128, 128, 128, 128, 128, 127, 127, 128, 128, 128, 128, 129, 128, 129, 128, 128, 128, 128, 128, 127, 127, 127, 127, 127, 126, 127, 127, 127, 127, 127, 127, 127, 127, 128, 128, 127, 127, 127, 128, 127, 127, 128, 127, 128, 128, 127, 127, 127, 128, 128, 127, 128, 129, 128, 127, 128, 127, 127, 127, 127, 127, 127, 128, 128, 127, 127, 127, 128, 127, 127, 127, 128, 127, 127, 127, 128, 128, 128, 128, 127, 128, 128, 128, 128, 128, 128, 128, 128, 128, 128, 128, 128, 128, 127, 127, 127, 127, 127, 127, 127, 127, 128, 127, 127, 127, 128, 128, 127, 127, 128, 128, 128, 128, 128, 128, 128, 128, 128, 128, 128, 127, 128, 128, 128, 128, 127, 127, 128, 128, 128, 128, 128, 128, 127, 127, 128, 128, 128, 127, 128, 128, 127, 127, 128, 128, 127, 128, 128, 127, 127, 127, 127, 127, 127, 127, 128, 128, 127, 128, 128, 127, 127, 128, 128, 127, 127, 127, 127, 127, 127, 128, 128, 128, 127, 128, 128, 127, 127, 128, 128, 128, 128, 128, 128, 127, 128, 128, 127, 127, 127, 128, 127, 127, 127, 128, 127, 127, 128, 128, 128, 128, 128, 128, 128, 127, 128, 128, 127, 127, 128, 128, 128, 127, 128, 128, 128, 127, 128, 128, 128, 127, 127, 128, 128, 127, 127, 128, 127, 127, 127, 127, 127, 127, 127, 127,
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

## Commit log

2024-05-06 nambah file arduino
2024-05-06 Add files via upload
    Studi Literatur (Clarrisa)
    [project gas.xlsx]
2024-05-06 Datsheet MQ2
    Sensor Mq2(Clarrisa)
2024-05-07 upload file 3D
    [alat 3d.blend]
2024-05-07 organisasi folder
    [alat 3d.blend, project gas.xlsx]
2024-05-12 Progress 2
    [EEPROM.kicad_sch, Project Hanip.kicad_pcb, Project Hanip.kicad_sch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]
2024-05-12 update progres 3D dengan Fusion
    [alat 3d.blend]
2024-05-13 menambah gambar skematik kicad
2024-05-14 nambah file 3D
    [Casing Gas 3D v5.stl]
2024-05-17 Schematic PCB
2024-05-17 PCB Board Design
2024-05-17 3D Design PCB
2024-05-17 PCB Schematic Update
2024-05-17 3D PCB File Design
    [Project Hanip.step]
2024-05-17 Schematic Update
2024-05-17 PCB Wizard Update
    [EEPROM.kicad_sch, Project Hanip.kicad_pcb, Project Hanip.kicad_sch]
2024-05-17 PCB Top
2024-05-17 PCB Silk Screen Update
2024-05-17 PCB Bottom Silk Screen Update
2024-05-17 PCB Bottom
2024-05-17 Progress 4 PCB
    [EEPROM.kicad_sch, Progress 4 Final.kicad_pcb, Progress 4 Final.kicad_sch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]
2024-05-17 update skematik PCB
2024-05-20 update file 3D
    [ATAS rev1.step, ATAS.step, BAWAH rev1.step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]
2024-05-25 Rearrange File and Folder
    [EEPROM.kicad_sch, Progress 4 Final.kicad_pcb, Progress 4 Final.kicad_sch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]
2024-05-28 update pcb
2024-05-28 update pin
2024-05-28 PCB Warna Warni
    [Progress 4 Final.kicad_pcb]
2024-06-03 menambahkan fungsi ADC pada bare Metal
2024-06-03 menyempurnakan fungsi ADC pada bare Metal
